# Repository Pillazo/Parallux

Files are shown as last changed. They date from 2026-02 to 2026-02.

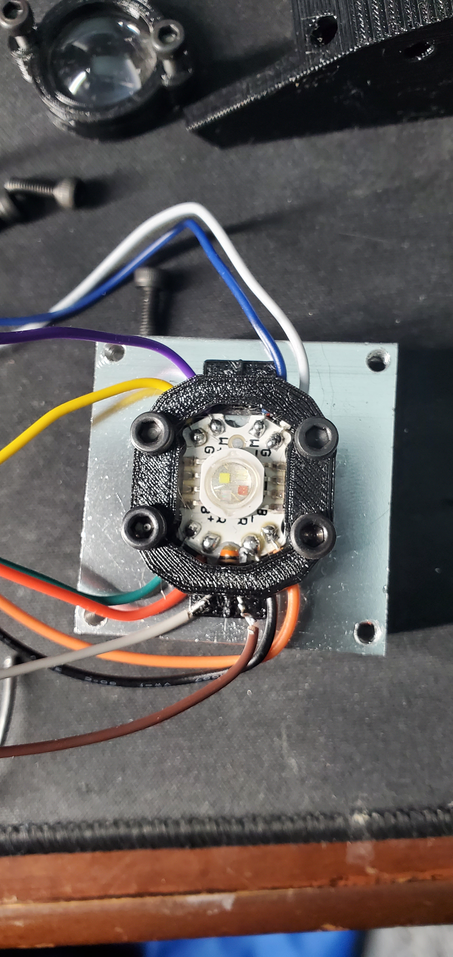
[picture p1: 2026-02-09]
LED Wires.jpg

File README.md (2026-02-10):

The light was designed in Autodesk Fusion 360, but any STEP editor will work. The step file is zipped because the full thing is 250gb-ish

The hardware was designed in KiCad 9.0

The software is arduino IDE, I used ESP32 and Teensy for the microcontrollers

The DMX controller software, which is more sACN anyways, was written in VB.NET

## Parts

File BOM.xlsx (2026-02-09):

Item | Qty | Set | Price per Set | Price | Sub Total | Total | Link
LEDs | 12 | 5 | 14.69 | 2.938 | 35.256 | 735.2235361 | https://www.amazon.com/dp/B0D91GZTSC (https://www.amazon.com/dp/B0D91GZTSC?ref=ppx_yo2ov_dt_b_fed_asin_title&th=1)
Buck Conv 3A | 17 | 8 | 8.89 | 1.11125 | 18.89125 |  | https://www.amazon.com/dp/B08DHS5XVK
Slip Ring | 1 | 1 | 26.58 | 26.58 | 26.58 |  | https://www.amazon.com/dp/B07QPNXXBQ
Lenses | 12 | 10 | 8.59 | 0.859 | 10.308 |  | https://www.amazon.com/dp/B0BR5Q6FN8
Mirrors | 24 | 120 | 9.99 | 0.08325 | 1.998 |  | https://www.amazon.com/dp/B07C1G5RKJ
Heat Sinks | 12 | 4 | 8.99 | 2.2475 | 26.97 |  | https://www.amazon.com/dp/B07SMX1DB7
Aluminum Rod | 1 | 1 | 9.99 | 9.99 | 9.99 |  | https://www.amazon.com/dp/B0CKXY1CXG
ESP32-C3 Super Mini | 4 | 10 | 29.99 | 2.999 | 11.996 |  | https://www.amazon.com/dp/B0DFWG87JS
Stepper Driver | 3 | 6 | 29.99 | 4.998333333 | 14.995 |  | https://www.amazon.com/dp/B08WZFK9KT
Large Steppers | 3 | 5 | 39.95 | 7.99 | 23.97 |  | https://www.amazon.com/dp/B0B38H2ZMR
Fans | 4 | 4 | 7.99 | 1.9975 | 7.99 |  | https://www.amazon.com/dp/B081338TWF
LED Cables | 12 | 10 | 8.99 | 0.899 | 10.788 |  | https://www.amazon.com/dp/B0D3LWW86H
Small Bearing | 28 | 20 | 7.98 | 0.399 | 11.172 |  | https://www.amazon.com/dp/B09PKD8QZZ
Small Steppers | 12 | 5 | 14.59 | 2.918 | 35.016 |  | https://www.amazon.com/dp/B00LPK0E5A
PowerCon Connectors | 1 | 1 | 9.98 | 9.98 | 9.98 |  | https://www.amazon.com/dp/B0CQVB3CF2
Power Supply | 1 | 1 | 28.54 | 28.54 | 28.54 |  | https://www.amazon.com/dp/B013ETVO12
Screw Terminals | 6 | 20 | 14.99 | 0.7495 | 4.497 |  | https://www.amazon.com/dp/B09F6TC7RP
Teensy 4.1 | 1 | 1 | 31.5 | 31.5 | 31.5 |  | https://www.sparkfun.com/teensy-4-1.html
Teensy Ethernet | 1 | 1 | 9.95 | 9.95 | 9.95 |  | https://www.sparkfun.com/ethernet-kit-for-teensy-4-1.html
M3x6mm | 32 | 180 | 7.99 | 0.04438888889 | 1.420444444 |  | https://www.amazon.com/dp/B0DJQGCS36
M3x10mm | 271 | 120 | 7.99 | 0.06658333333 | 18.04408333 |  | https://www.amazon.com/dp/B0DJQGGDP2
M4x6mm | 35 | 120 | 7.99 | 0.06658333333 | 2.330416667 |  | https://www.amazon.com/dp/B0DYS5W46C
M4x12mm | 126 | 120 | 8.49 | 0.07075 | 8.9145 |  | https://www.amazon.com/dp/B0DYRZQQZT
M4x12 Flat Head | 16 | 100 | 8.28 | 0.0828 | 1.3248 |  | https://www.amazon.com/dp/B0CTHK3NLP
M4x20mm | 28 | 120 | 8.99 | 0.07491666667 | 2.097666667 |  | https://www.amazon.com/dp/B0DYSQZHC9
M4x30 Flat Head | 16 | 50 | 8.59 | 0.1718 | 2.7488 |  | https://www.amazon.com/dp/B0FWCTL3XG
m4X35mm | 2 | 60 | 8.49 | 0.1415 | 0.283 |  | https://www.amazon.com/dp/B0DYNFH87B
M6x25mm | 108 | 50 | 8.54 | 0.1708 | 18.4464 |  | https://www.amazon.com/dp/B0FX3Z9DPT
M6x40mm | 56 | 30 | 8.54 | 0.2846666667 | 15.94133333 |  | https://www.amazon.com/dp/B0FX425KPN
M10x30mm | 9 | 10 | 8.79 | 0.879 | 7.911 |  | https://www.amazon.com/dp/B0DJS5RGWF
M10x40mm | 18 | 12 | 12.19 | 1.015833333 | 18.285 |  | https://www.amazon.com/dp/B0DFYL4ZWN
M10x70mm | 19 | 6 | 9.99 | 1.665 | 31.635 |  | https://www.amazon.com/dp/B0D83CJF9C
M3 Nyloc | 7 | 120 | 5.99 | 0.04991666667 | 0.3494166667 |  | https://www.amazon.com/dp/B0D146SHYF
Flat Bearing | 1 | 2 | 9.99 | 4.995 | 4.995 |  | https://www.amazon.com/dp/B0F9B1SBCT
Big Bearing | 5 | 20 | 21.99 | 1.0995 | 5.4975 |  | https://www.amazon.com/dp/B0D5M2LNSG
Aluminum Extrusion 385mm | 2 | 1 | 15.47 | 15.47 | 30.94 |  | https://www.amazon.com/dp/B00J7W1A6U
Aluminum Extrusion 475mm | 5 | 1 | 15.47 | 15.47 | 77.35 |  | https://www.amazon.com/dp/B00J7W1A6U
LightDisc Board | 4 | 10 | 80 | 8 | 32
Thermistor | 12 | 1 | 0.474 | 0.474 | 5.688 |  | https://www.digikey.com/en/products/detail/vishay-beyschlag-draloric-bc-components/NTCLE100E3103JB0/769411
LED Driver | 48 | 1 | 0.3624 | 0.3624 | 17.3952 |  | https://www.digikey.com/en/products/detail/diodes-incorporated/AL8860WT-7/6226978
10K Resistor | 66 | 1 | 0.0112 | 0.0112 | 0.7392 |  | https://www.digikey.com/en/products/detail/yageo/RC1206FR-0710KL/728483
0.015 Resistor | 50 | 1 | 0.098 | 0.098 | 4.9 |  | https://www.digikey.com/en/products/detail/susumu/RL1220T-R015-J/714248
PCA PWM Chip | 4 | 1 | 3.03 | 3.03 | 12.12 |  | https://www.digikey.com/en/products/detail/nxp-usa-inc/PCA9685PW-Q900-118/2406198
MCP IO Chip | 4 | 1 | 1.62 | 1.62 | 6.48 |  | https://www.digikey.com/en/products/detail/microchip-technology/MCP23017-E-SO/894271
Connector 6 Pin | 5 | 1 | 1.88 | 1.88 | 9.4 |  | https://www.digikey.com/en/products/detail/phoenix-contact/1988846/950896
Inductor | 48 | 1 | 0.28 | 0.28 | 13.44 |  | https://www.digikey.com/en/products/detail/tdk-corporation/VLS6045EX-330M/5286699
Diode Schottky | 60 | 1 | 0.207 | 0.207 | 12.42 |  | https://www.digikey.com/en/products/detail/stmicroelectronics/1N5819/1037326
2.2uf Cap | 50 | 1 | 0.0396 | 0.0396 | 1.98 |  | https://www.digikey.com/en/products/detail/samsung-electro-mechanics/CL21B225KPFNNNE/3886846
1uf Cap | 50 | 1 | 0.009 | 0.009 | 0.45 |  | https://www.digikey.com/en/products/detail/samsung-electro-mechanics/CL21B105KAFNNNE/3886724
0.1uf Cap | 10 | 1 | 0.006 | 0.006 | 0.06 |  | https://www.digikey.com/en/products/detail/samsung-electro-mechanics/CL21B104KBCNNNC/3886661
2.2k resistor | 10 | 1 | 0.047 | 0.047 | 0.47 |  | https://www.digikey.com/en/products/detail/te-connectivity-passive-product/CRGCQ1206F2K2/8576416
10uf Cap | 5 | 1 | 0.137 | 0.137 | 0.685 |  | https://www.digikey.com/en/products/detail/panasonic-electronic-components/ECA-1EM100/245007
100uf Cap | 17 | 1 | 0.134 | 0.134 | 2.278 |  | https://www.digikey.com/en/products/detail/panasonic-electronic-components/ECA-0JM101I/2688620
330uf Cap | 4 | 1 | 0.29 | 0.29 | 1.16 |  | https://www.digikey.com/en/products/detail/chinsan-elite/EK1V331MP51012U/16496951
Price per PETG kg: | 13.5
 |  |  |  |  |  |  | Time
 | Qty | grams | PPKG |  |  |  | Hours | Minutes | Total Minutes | Total Time: | 13066
Front Face | 4 | 40.16 | 13.5 | 0.54216 | 2.16864 |  | 3 | 24 | 816 | Hours | 217 | Days: | 9.041666667
Face Star | 1 | 10.8 | 13.5 | 0.1458 | 0.1458 |  |  | 57 | 57 | Minutes | 46
Front Lens Cover | 12 | 6.79 | 13.5 | 0.091665 | 1.09998 |  |  | 40 | 480
Rear Frame x12 | 1 | 12.97 | 13.5 | 0.175095 | 0.175095 |  | 1 | 26 | 86
Front Frame x24 | 1 | 18.11 | 13.5 | 0.244485 | 0.244485 |  | 2 | 3 | 123
Wire Fixture Top x12 | 1 | 12.55 | 13.5 | 0.169425 | 0.169425 |  | 1 | 33 | 93
Wire Fixture Bot x12 | 1 | 6.27 | 13.5 | 0.084645 | 0.084645 |  |  | 50 | 50
Frame | 12 | 20.55 | 13.5 | 0.277425 | 3.3291 |  | 1 | 54 | 1368
Mirror Holder | 12 | 13.06 | 13.5 | 0.17631 | 2.11572 |  | 1 | 9 | 828
Ring Section Single | 4 | 12.9 | 13.5 | 0.17415 | 0.6966 |  | 1 | 15 | 300
Ring Section Dual | 4 | 34.34 | 13.5 | 0.46359 | 1.85436 |  | 3 | 16 | 784
Back Face | 4 | 46.78 | 13.5 | 0.63153 | 2.52612 |  | 4 | 3 | 972
Disc Ring Gear | 4 | 10.59 | 13.5 | 0.142965 | 0.57186 |  | 1 | 1 | 244
Shim - Ironed | 2 | 3.91 | 13.5 | 0.052785 | 0.10557 |  | 1 | 0 | 120
Center Cover Bolts | 1 | 77.91 | 13.5 | 1.051785 | 1.051785 |  | 6 | 15 | 375
Center Cover Threaded | 1 | 78.39 | 13.5 | 1.058265 | 1.058265 |  | 6 | 5 | 365
Inner Shim | 1 | 0.5 | 13.5 | 0.00675 | 0.00675 |  | 0 | 4 | 4
Disc Inner Gear | 1 | 11.17 | 13.5 | 0.150795 | 0.150795 |  | 0 | 59 | 59
Slip Ring Connector | 1 | 10.5 | 13.5 | 0.14175 | 0.14175 |  | 0 | 54 | 54
Motor Mount Adapter | 1 | 22.36 | 13.5 | 0.30186 | 0.30186 |  | 1 | 47 | 107
Disc Mount | 1 | 24.99 | 13.5 | 0.337365 | 0.337365 |  | 2 | 12 | 132
Wire Cap x6 | 1 | 3.32 | 13.5 | 0.04482 | 0.04482 |  | 0 | 23 | 23
Wire Cap Front | 1 | 0.72 | 13.5 | 0.00972 | 0.00972 |  | 0 | 7 | 7
Counter weight | 1 | 194.17 | 13.5 | 2.621295 | 2.621295 |  | 14 | 57 | 897
Ring Drive Gear | 2 | 28.65 | 13.5 | 0.386775 | 0.77355 |  | 2 | 17 | 274
Tilt Cap | 2 | 8.77 | 13.5 | 0.118395 | 0.23679 |  | 0 | 48 | 96
tilt Motor Mount | 1 | 27.55 | 13.5 | 0.371925 | 0.371925 |  | 2 | 14 | 134
Motor Mount Offset 1 | 1 | 7.27 | 13.5 | 0.098145 | 0.098145 |  | 0 | 41 | 41
Motor Mount Offset 2 | 1 | 6.88 | 13.5 | 0.09288 | 0.09288 |  | 0 | 39 | 39
Tilt Upright 1 Lower | 1 | 97.65 | 13.5 | 1.318275 | 1.318275 |  | 6 | 55 | 415
Tilt Upright 1 Upper | 1 | 36.12 | 13.5 | 0.48762 | 0.48762 |  | 2 | 49 | 169
Tilt Upright 2 Lower | 1 | 96.46 | 13.5 | 1.30221 | 1.30221 |  | 6 | 41 | 401
Tilt Upright 2 Upper | 1 | 35.89 | 13.5 | 0.484515 | 0.484515 |  | 2 | 50 | 170
Pipe Cap | 1 | 11.32 | 13.5 | 0.15282 | 0.15282 |  | 0 | 54 | 54
Tilt Gear 1 | 1 | 57.52 | 13.5 | 0.77652 | 0.77652 |  | 4 | 40 | 280
Tilt Gear 2 | 1 | 57.58 | 13.5 | 0.77733 | 0.77733 |  | 4 | 41 | 281
Pan Gear Mount | 2 | 101.31 | 13.5 | 1.367685 | 2.73537 |  | 7 | 30 | 900
Pan Gear Idle | 2 | 92.7 | 13.5 | 1.25145 | 2.5029 |  | 7 | 0 | 840
Pan Center | 1 | 2.95 | 13.5 | 0.039825 | 0.039825 |  | 0 | 21 | 21
Cable Chain x10 | 1 | 12.07 | 13.5 | 0.162945 | 0.162945 |  | 1 | 23 | 83
Cable Chain Base | 1 | 3.46 | 13.5 | 0.04671 | 0.04671 |  | 0 | 24 | 24
Pan Base Mount | 1 | 24.89 | 13.5 | 0.336015 | 0.336015 |  | 2 | 2 | 122
Pan Chain Attach Holes | 1 | 5.4 | 13.5 | 0.0729 | 0.0729 |  | 0 | 32 | 32
Pan Chain Attach Threaded | 1 | 5.03 | 13.5 | 0.067905 | 0.067905 |  | 0 | 29 | 29
Power Supply Mount x4 | 1 | 17.45 | 13.5 | 0.235575 | 0.235575 |  | 1 | 33 | 93
PS Cover Upper | 1 | 20.17 | 13.5 | 0.272295 | 0.272295 |  | 1 | 47 | 107
PS Cover Lower | 1 | 22.2 | 13.5 | 0.2997 | 0.2997 |  | 1 | 57 | 117
 |  |  | 13.5 | 0 | 0 |  |  |  | 0
 |  |  | 13.5 | 0 | 0 |  |  |  | 0
 |  |  | 13.5 | 0 | 0 |  |  |  | 0
 |  |  | 13.5 | 0 | 0 |  |  |  | 0
 |  |  | 13.5 | 0 | 0 |  |  |  | 0
 |  |  | 13.5 | 0 | 0 |  |  |  | 0
 |  |  | 13.5 | 0 | 0 |  |  |  | 0
 |  |  | 13.5 | 0 | 0 |  |  |  | 0
 |  |  | 13.5 | 0 | 0 |  |  |  | 0
 |  |  | 13.5 | 0 | 0 |  |  |  | 0

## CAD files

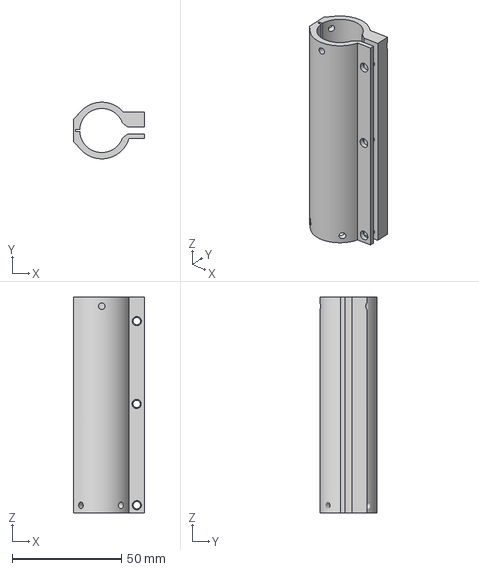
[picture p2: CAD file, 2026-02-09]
3MF Files/CenterPostGuide.3mf
32.6 x 26.0 x 99.0 mm

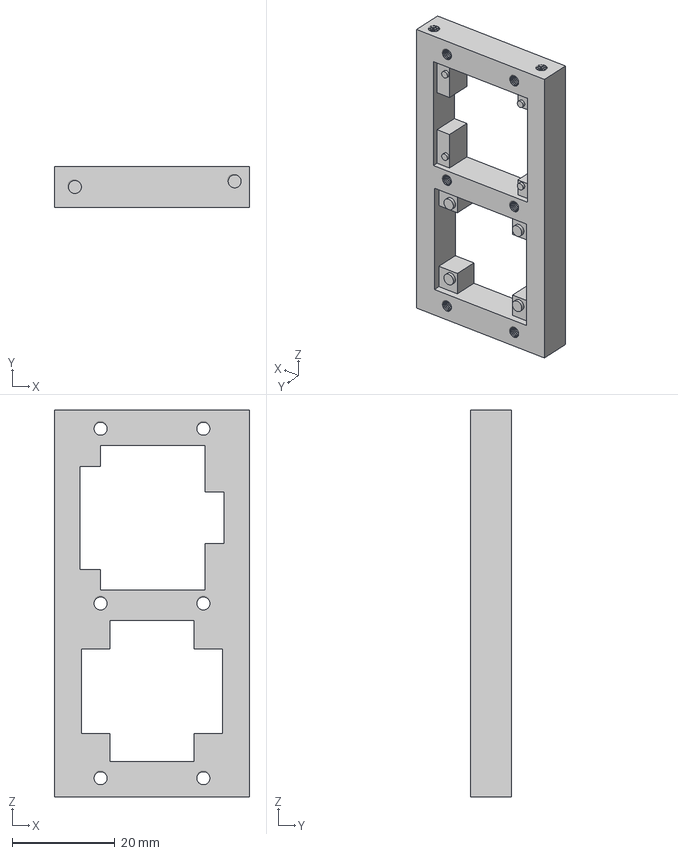
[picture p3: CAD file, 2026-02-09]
3MF Files/NaviBase.3mf
38.0 x 8.00 x 75.3 mm

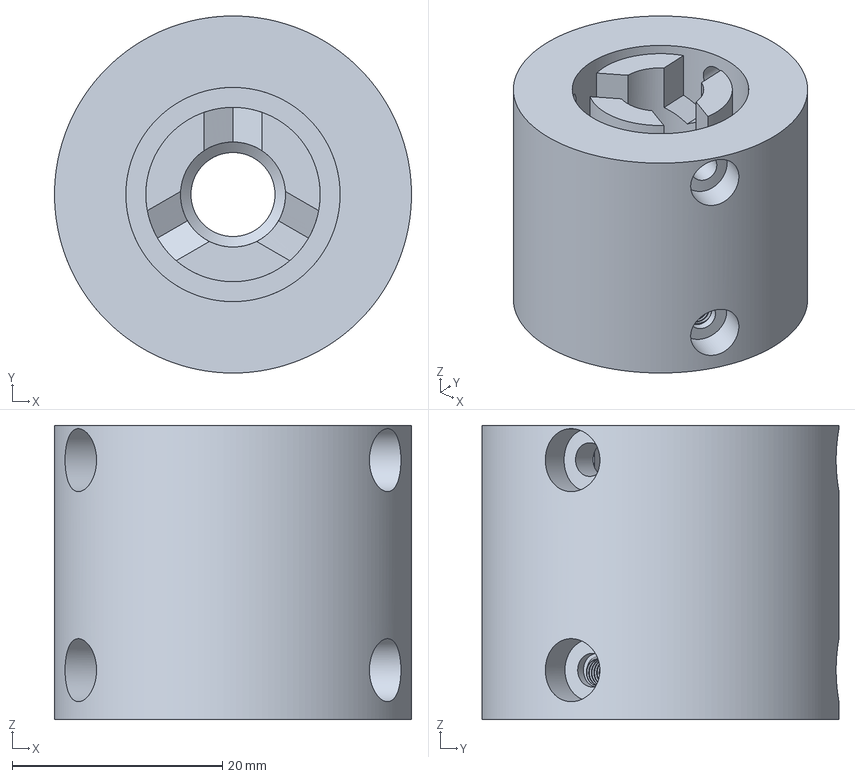
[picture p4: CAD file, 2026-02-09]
3MF Files/SlipRing Connector.3mf
34.0 x 34.0 x 28.0 mm

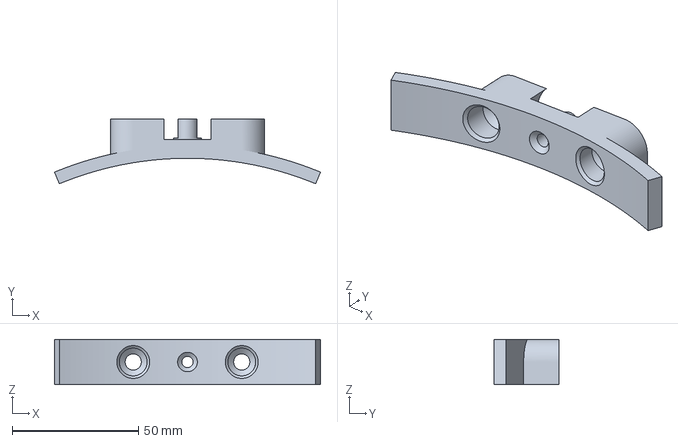
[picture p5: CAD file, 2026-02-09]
3MF Files/Pan Bearing CapSlide.3mf
105.4 x 25.6 x 18.0 mm

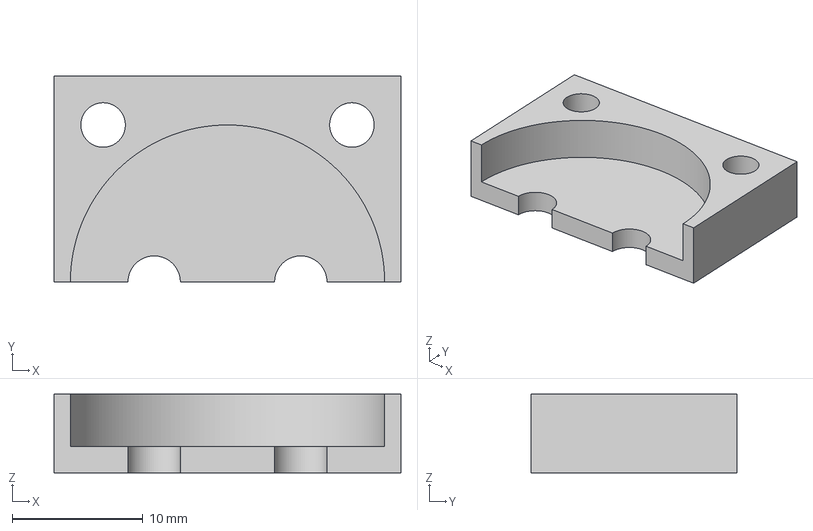
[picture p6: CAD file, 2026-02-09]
3MF Files/PowerConBack.3mf
26.5 x 15.8 x 6.00 mm

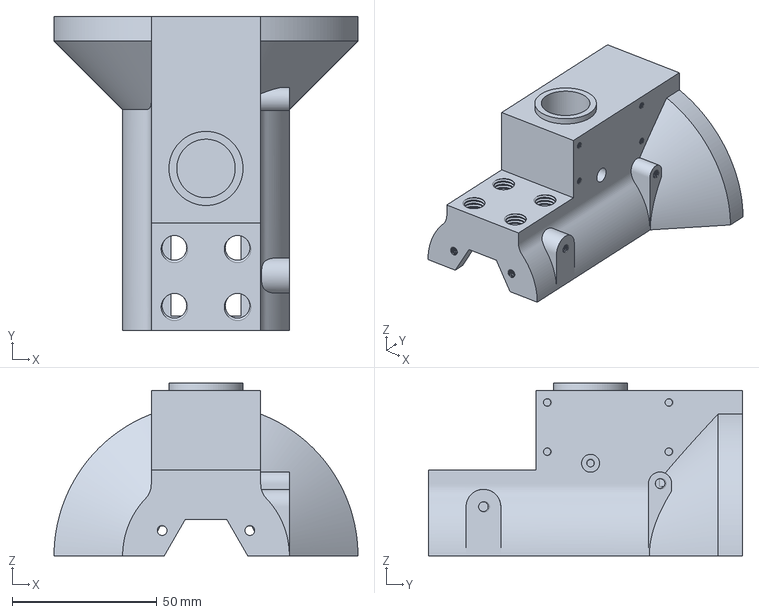
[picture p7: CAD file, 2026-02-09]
3MF Files/CenterCoverThreaded.3mf
105.0 x 108.5 x 59.7 mm

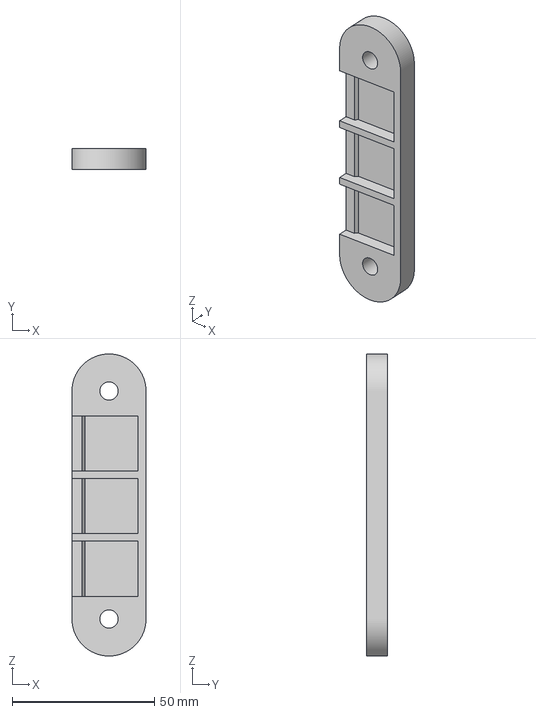
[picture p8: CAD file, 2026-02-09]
3MF Files/WagoHolder Back.3mf
26.0 x 7.50 x 106.0 mm

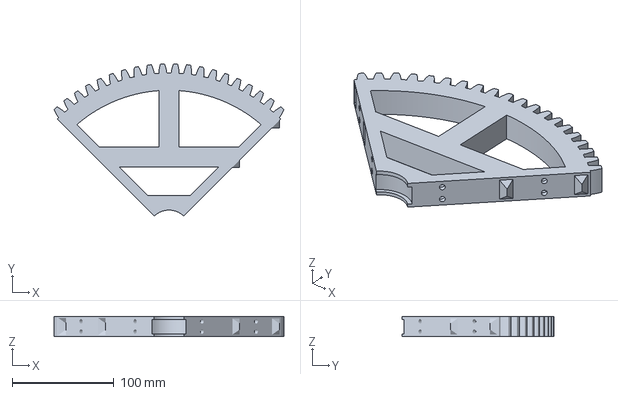
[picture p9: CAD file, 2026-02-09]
3MF Files/Pan Gear Idle 2.3mf
225.5 x 149.4 x 20.0 mm

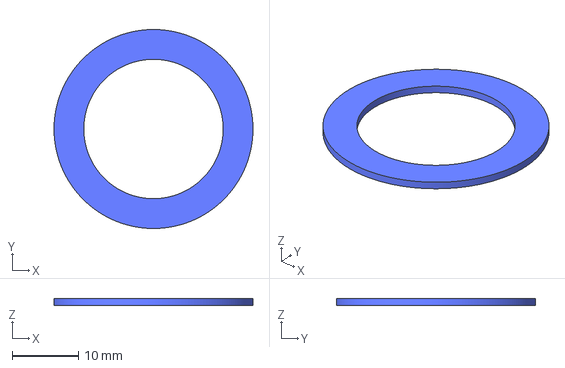
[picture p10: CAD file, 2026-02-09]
3MF Files/Inner Shim.3mf
30.0 x 30.0 x 1.00 mm

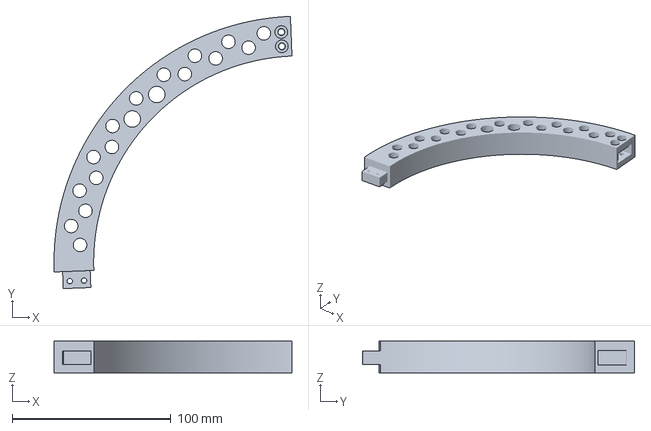
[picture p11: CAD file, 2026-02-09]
3MF Files/TiltRingGearAttach.3mf
149.9 x 171.4 x 20.0 mm

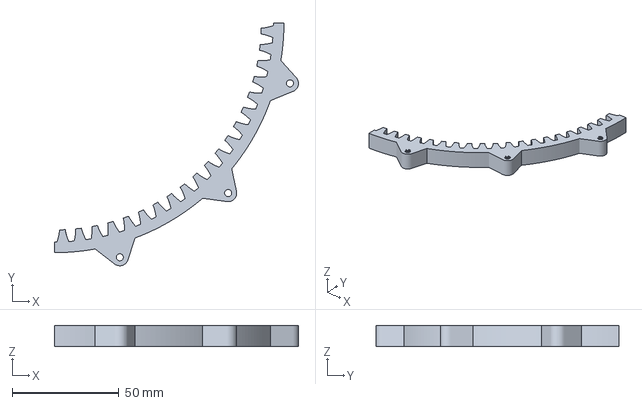
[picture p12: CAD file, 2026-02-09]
3MF Files/Disc Ring Gear.3mf
114.2 x 113.6 x 10.0 mm

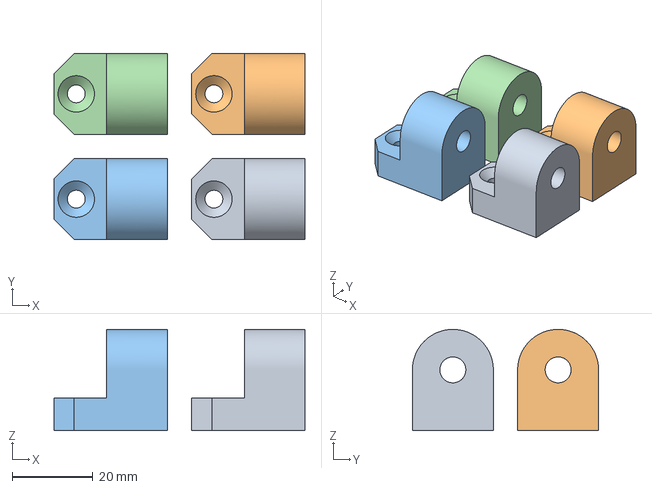
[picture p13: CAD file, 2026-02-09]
3MF Files/PowerSupplyMount.3mf
62.0 x 46.0 x 25.0 mm

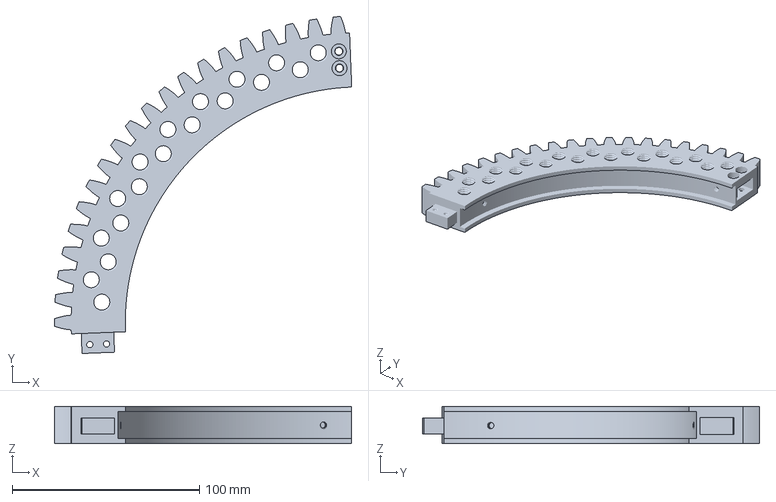
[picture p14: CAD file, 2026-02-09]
3MF Files/Tilt Ring Gear Section.3mf
159.1 x 180.2 x 20.0 mm

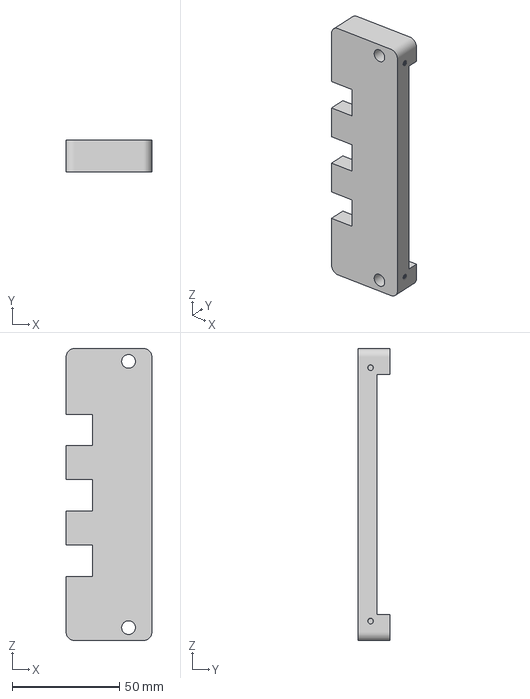
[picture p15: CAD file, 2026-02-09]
3MF Files/Electronics Mount 1.3mf
40.0 x 14.8 x 136.0 mm

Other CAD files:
3MF Files/Panel Connector Right.3mf
3MF Files/Pan Bearing Holder Front.3mf
3MF Files/Tilt Gear 1.3mf
3MF Files/Electronics Mount 2.3mf
3MF Files/Aluminum Nut 2x 16mm.3mf
3MF Files/Aluminum Nut.3mf
3MF Files/Axel Key.3mf
3MF Files/Back Face.3mf
3MF Files/Base Joiner Corner.3mf
3MF Files/Base Joiner Lower.3mf
3MF Files/Base Joiner Upper Enet.3mf
3MF Files/Base Joiner Upper-PC.3mf
3MF Files/Base Joiner Upper.3mf
3MF Files/Bearing Cap.3mf
3MF Files/CBSheelThreads.3mf
3MF Files/CBShellHole.3mf
3MF Files/Cable Chain Base.3mf
3MF Files/Cable Chain.3mf
3MF Files/CenterCoverBolts.3mf
3MF Files/Disc Inner Gear.3mf
3MF Files/DiscMount.3mf
3MF Files/Electronics Lid.3mf
3MF Files/EthernetLid.3mf
3MF Files/FacePlateStar.3mf
3MF Files/Fan Grill.3mf
3MF Files/Frame.3mf
3MF Files/FrontFace.3mf
3MF Files/FrontFrame.3mf
3MF Files/FrontLensCover.3mf
3MF Files/MirrorHolder.3mf
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

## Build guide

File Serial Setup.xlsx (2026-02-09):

Index | DMX Address | From Master Chip | From Board 1 | From Board 2 | From Board 3 | From Board 4
0 | 1 | D | D | D | D | D
1 | 2 | Light 1 Hue | Light 4 Hue | Light 7 Hue | Light 10 Hue | Light 1 Temp Ch1
2 | 3 | Light 1 Sat | Light 4 Sat | Light 7 Sat | Light 10 Sat | Light 1 Temp Ch2
3 | 4 | Light 1 Value | Light 4 Value | Light 7 Value | Light 10 Value | Light 1 Temp Per
4 | 5 | Light 1 Mirror | Light 4 Mirror | Light 7 Mirror | Light 10 Mirror | Light 1 Temp Ch3
5 | 6 | Light 2 Hue | Light 5 Hue | Light 8 Hue | Light 11 Hue | Light 2 Temp Ch1
6 | 7 | Light 2 Sat | Light 5 Sat | Light 8 Sat | Light 11 Sat | Light 2 Temp Ch2
7 | 8 | Light 2 Value | Light 5 Value | Light 8 Value | Light 11 Value | Light 2 Temp Per
8 | 9 | Light 2 Mirror | Light 5 Mirror | Light 8 Mirror | Light 11 Mirror | Light 2 Temp Ch3
9 | 10 | Light 3 Hue | Light 6 Hue | Light 9 Hue | Light 12 Hue | Light 3 Temp Ch1
10 | 11 | Light 3 Sat | Light 6 Sat | Light 9 Sat | Light 12 Sat | Light 3 Temp Ch2
11 | 12 | Light 3 Value | Light 6 Value | Light 9 Value | Light 12 Value | Light 3 Temp Per
12 | 13 | Light 3 Mirror | Light 6 Mirror | Light 9 Mirror | Light 12 Mirror | Light 3 Temp Ch3
13 | 14 | Light 4 Hue | Light 7 Hue | Light 10 Hue | Light 1 Temp Ch1 | Light 4 Temp Ch1
14 | 15 | Light 4 Sat | Light 7 Sat | Light 10 Sat | Light 1 Temp Ch2 | Light 4 Temp Ch2
15 | 16 | Light 4 Value | Light 7 Value | Light 10 Value | Light 1 Temp Per | Light 4 Temp Per
16 | 17 | Light 4 Mirror | Light 7 Mirror | Light 10 Mirror | Light 1 Temp Ch3 | Light 4 Temp Ch3
17 | 18 | Light 5 Hue | Light 8 Hue | Light 11 Hue | Light 2 Temp Ch1 | Light 5 Temp Ch1
18 | 19 | Light 5 Sat | Light 8 Sat | Light 11 Sat | Light 2 Temp Ch2 | Light 5 Temp Ch2
19 | 20 | Light 5 Value | Light 8 Value | Light 11 Value | Light 2 Temp Per | Light 5 Temp Per
20 | 21 | Light 5 Mirror | Light 8 Mirror | Light 11 Mirror | Light 2 Temp Ch3 | Light 5 Temp Ch3
21 | 22 | Light 6 Hue | Light 9 Hue | Light 12 Hue | Light 3 Temp Ch1 | Light 6 Temp Ch1
22 | 23 | Light 6 Sat | Light 9 Sat | Light 12 Sat | Light 3 Temp Ch2 | Light 6 Temp Ch2
23 | 24 | Light 6 Value | Light 9 Value | Light 12 Value | Light 3 Temp Per | Light 6 Temp Per
24 | 25 | Light 6 Mirror | Light 9 Mirror | Light 12 Mirror | Light 3 Temp Ch3 | Light 6 Temp Ch3
25 | 26 | Light 7 Hue | Light 10 Hue | Light 1 Temp Ch1 | Light 4 Temp Ch1 | Light 7 Temp Ch1
26 | 27 | Light 7 Sat | Light 10 Sat | Light 1 Temp Ch2 | Light 4 Temp Ch2 | Light 7 Temp Ch2
27 | 28 | Light 7 Value | Light 10 Value | Light 1 Temp Per | Light 4 Temp Per | Light 7 Temp Per
28 | 29 | Light 7 Mirror | Light 10 Mirror | Light 1 Temp Ch3 | Light 4 Temp Ch3 | Light 7 Temp Ch3
29 | 30 | Light 8 Hue | Light 11 Hue | Light 2 Temp Ch1 | Light 5 Temp Ch1 | Light 8 Temp Ch1
30 | 31 | Light 8 Sat | Light 11 Sat | Light 2 Temp Ch2 | Light 5 Temp Ch2 | Light 8 Temp Ch2
31 | 32 | Light 8 Value | Light 11 Value | Light 2 Temp Per | Light 5 Temp Per | Light 8 Temp Per
32 | 33 | Light 8 Mirror | Light 11 Mirror | Light 2 Temp Ch3 | Light 5 Temp Ch3 | Light 8 Temp Ch3
33 | 34 | Light 9 Hue | Light 12 Hue | Light 3 Temp Ch1 | Light 6 Temp Ch1 | Light 9 Temp Ch1
34 | 35 | Light 9 Sat | Light 12 Sat | Light 3 Temp Ch2 | Light 6 Temp Ch2 | Light 9 Temp Ch2
35 | 36 | Light 9 Value | Light 12 Value | Light 3 Temp Per | Light 6 Temp Per | Light 9 Temp Per
36 | 37 | Light 9 Mirror | Light 12 Mirror | Light 3 Temp Ch3 | Light 6 Temp Ch3 | Light 9 Temp Ch3
37 | 38 | Light 10 Hue | Light 1 Temp Ch1 | Light 4 Temp Ch1 | Light 7 Temp Ch1 | Light 10 Temp Ch1
38 | 39 | Light 10 Sat | Light 1 Temp Ch2 | Light 4 Temp Ch2 | Light 7 Temp Ch2 | Light 10 Temp Ch2
39 | 40 | Light 10 Value | Light 1 Temp Per | Light 4 Temp Per | Light 7 Temp Per | Light 10 Temp Per
40 | 41 | Light 10 Mirror | Light 1 Temp Ch3 | Light 4 Temp Ch3 | Light 7 Temp Ch3 | Light 10 Temp Ch3
41 | 42 | Light 11 Hue | Light 2 Temp Ch1 | Light 5 Temp Ch1 | Light 8 Temp Ch1 | Light 11 Temp Ch1
42 | 43 | Light 11 Sat | Light 2 Temp Ch2 | Light 5 Temp Ch2 | Light 8 Temp Ch2 | Light 11 Temp Ch2
43 | 44 | Light 11 Value | Light 2 Temp Per | Light 5 Temp Per | Light 8 Temp Per | Light 11 Temp Per
44 | 45 | Light 11 Mirror | Light 2 Temp Ch3 | Light 5 Temp Ch3 | Light 8 Temp Ch3 | Light 11 Temp Ch3
45 | 46 | Light 12 Hue | Light 3 Temp Ch1 | Light 6 Temp Ch1 | Light 9 Temp Ch1 | Light 12 Temp Ch1
46 | 47 | Light 12 Sat | Light 3 Temp Ch2 | Light 6 Temp Ch2 | Light 9 Temp Ch2 | Light 12 Temp Ch2
47 | 48 | Light 12 Value | Light 3 Temp Per | Light 6 Temp Per | Light 9 Temp Per | Light 12 Temp Per
48 | 49 | Light 12 Mirror | Light 3 Temp Ch3 | Light 6 Temp Ch3 | Light 9 Temp Ch3 | Light 12 Temp Ch3
49 | 50
50 | 51
51 | 52
52 | 53
53 | 54
54 | 55
55 | 56
56 | 57
57 | 58
58 | 59
59 | 60
60 | 61
61 | 62
62 | 63
63 | 64
64 | 65
65 | 66
66 | 67
67 | 68
68 | 69
69 | 70

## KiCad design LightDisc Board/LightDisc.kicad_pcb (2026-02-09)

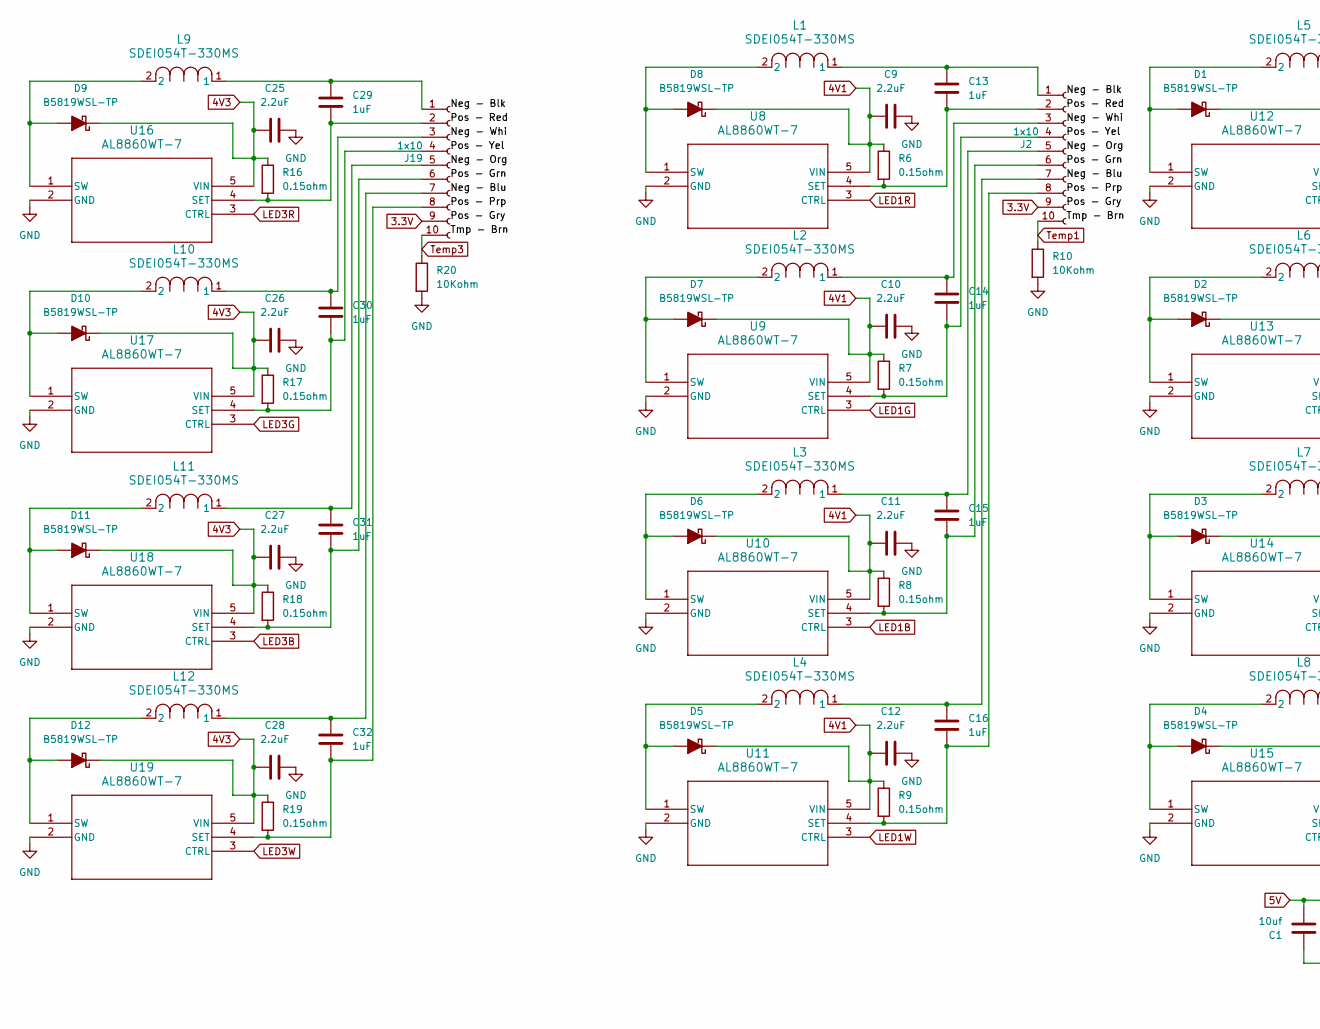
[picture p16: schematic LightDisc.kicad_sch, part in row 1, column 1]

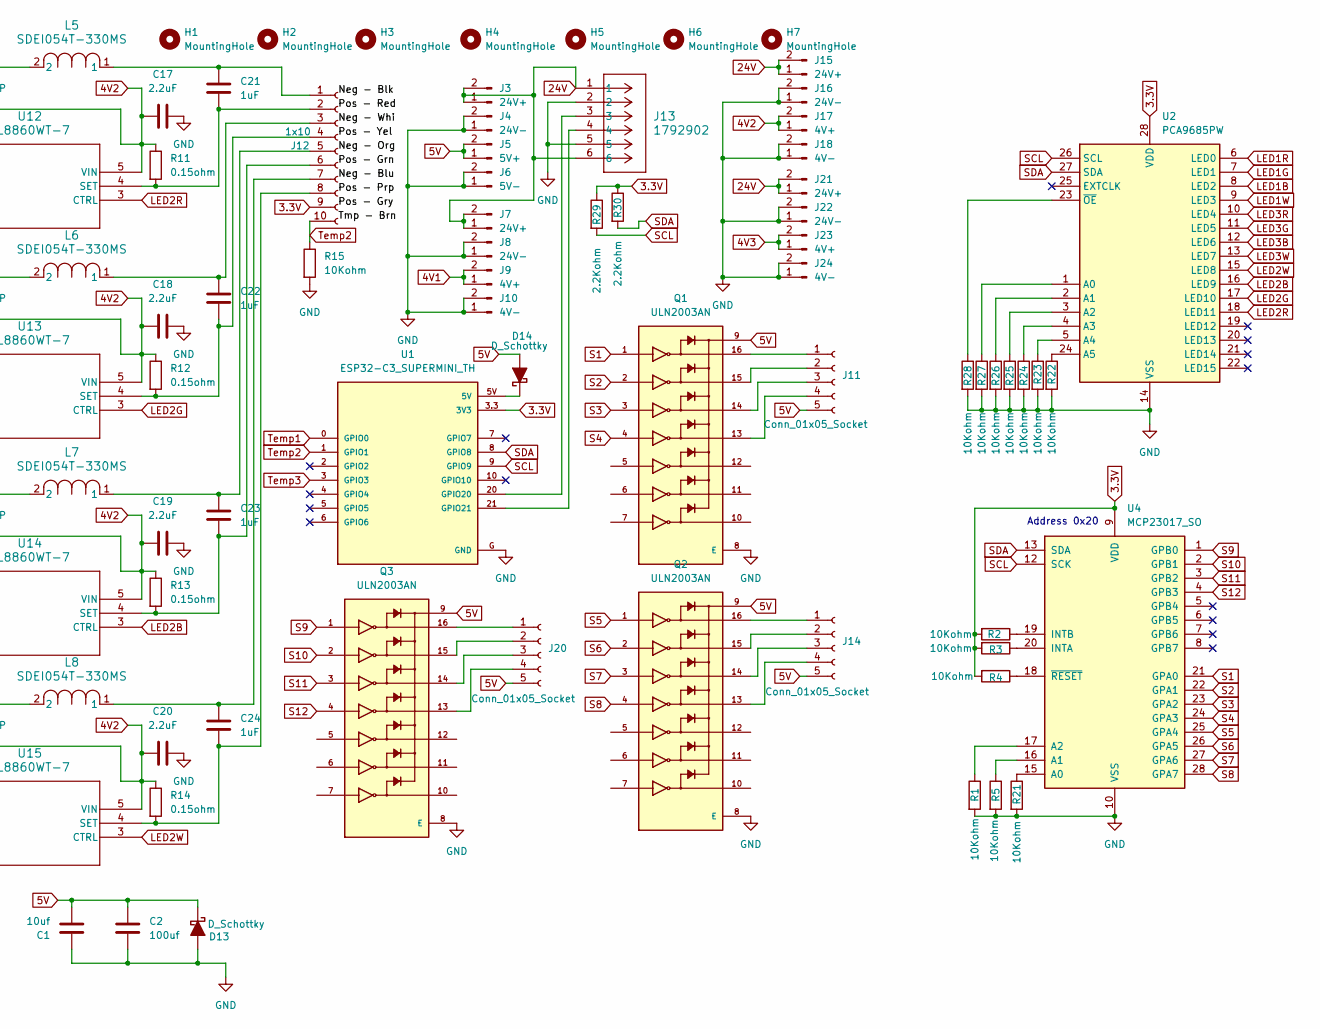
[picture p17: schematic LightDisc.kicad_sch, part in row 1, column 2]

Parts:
C1: 10uf; CP_Radial_D5.0mm_P2.50mm
C2: 100uf; CP_Radial_D5.0mm_P2.50mm
C9, C10, C11, C12, C17, C18, C19, C20, C25, C26, C27, C28: 2.2uF; C_0603_1608Metric
C13, C14, C15, C16, C21, C22, C23, C24, C29, C30, C31, C32: 1uF; C_0603_1608Metric
D1, D2, D3, D4, D5, D6, D7, D8, D9, D10, D11, D12: B5819WSL-TP; D_SOD-323F
D13, D14: D_Schottky; D_SOD-323F
H1, H2, H3, H4, H5, H6, H7: MountingHole; MountingHole_3.2mm_M3
J2, J12, J19: 1x10; JST_EH_B10B-EH-A_1x10_P2.50mm_Vertical
J3, J7, J15, J21: 24V+; PinSocket_1x02_P2.54mm_Vertical
J4, J8, J16, J22: 24V-; PinSocket_1x02_P2.54mm_Vertical
J5: 5V+; PinSocket_1x02_P2.54mm_Vertical
J6: 5V-; PinSocket_1x02_P2.54mm_Vertical
J9, J17, J23: 4V+; PinSocket_1x02_P2.54mm_Vertical
J10, J18, J24: 4V-; PinSocket_1x02_P2.54mm_Vertical
J11, J14, J20: Conn_01x05_Socket; PinSocket_1x05_P2.54mm_Vertical
J13: 1792902; CONN_1792902_PXC
L1, L2, L3, L4, L5, L6, L7, L8, L9, L10, L11, L12: SDEI054T-330MS; IND_SDEI054T-330MS_CYN
Q1, Q2, Q3: ULN2003AN; CERDIP-16_W7.62mm_SideBrazed_LongPads_Socket; PARTREV P
R1, R2, R3, R4, R5, R10, R15, R20, R21, R22, R23, R24, R25, R26, R27, R28: 10Kohm; R_1206_3216Metric
R6, R7, R8, R9, R11, R12, R13, R14, R16, R17, R18, R19: 0.15ohm; R_0805_2012Metric
R29, R30: 2.2Kohm; R_1206_3216Metric
U1: ESP32-C3_SUPERMINI_TH; MODULE_ESP32-C3_SUPERMINI_TH
U2: PCA9685PW; TSSOP-28_4.4x9.7mm_P0.65mm
U4: MCP23017_SO; SOIC-28W_7.5x17.9mm_P1.27mm
U8, U9, U10, U11, U12, U13, U14, U15, U16, U17, U18, U19: AL8860WT-7; TSOT25_WT_DIO

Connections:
3.3V: J2.9, J12.9, J19.9, R2.2, R3.2, R4.2, R29.1, R30.1, U1.3.3 (3V3), U2.28 (VDD), U4.9 (VDD)
4V1: C9.2, C10.2, C11.2, C12.2, D5.1 (K), D6.1 (K), D7.1 (K), D8.1 (K), J9.1, J9.2, R6.1, R7.1, R8.1, R9.1, U8.5 (VIN), U9.5 (VIN), U10.5 (VIN), U11.5 (VIN)
4V2: C17.2, C18.2, C19.2, C20.2, D1.1 (K), D2.1 (K), D3.1 (K), D4.1 (K), J17.1, J17.2, R11.1, R12.1, R13.1, R14.1, U12.5 (VIN), U13.5 (VIN), U14.5 (VIN), U15.5 (VIN)
4V3: C25.2, C26.2, C27.2, C28.2, D9.1 (K), D10.1 (K), D11.1 (K), D12.1 (K), J23.1, J23.2, R16.1, R17.1, R18.1, R19.1, U16.5 (VIN), U17.5 (VIN), U18.5 (VIN), U19.5 (VIN)
5V: C1.2, C2.2, D13.1 (K), D14.2 (A), J5.1, J5.2, J11.5, J14.5, J20.5, Q1.9, Q2.9, Q3.9
24V: J3.1, J3.2, J7.1, J7.2, J13.1, J13.6, J15.1, J15.2, J21.1, J21.2
GND: C1.1, C2.1, C9.1, C10.1, C11.1, C12.1, C17.1, C18.1, C19.1, C20.1, C25.1, C26.1, C27.1, C28.1, D13.2 (A), J4.1, J4.2, J6.1, J6.2, J8.1, J8.2, J10.1, J10.2, J13.2, J13.5, J16.1, J16.2, J18.1, J18.2, J22.1, J22.2, J24.1, J24.2, Q1.8 (E), Q2.8 (E), Q3.8 (E), R1.2, R5.2, R10.2, R15.2, R20.2, R21.2, R22.2, R23.2, R24.2, R25.2, R26.2, R27.2, R28.2, U1.G (GND), U2.14 (VSS), U4.10 (VSS), U8.2 (GND), U9.2 (GND), U10.2 (GND), U11.2 (GND), U12.2 (GND), U13.2 (GND), U14.2 (GND), U15.2 (GND), U16.2 (GND), U17.2 (GND), U18.2 (GND), U19.2 (GND)
LED1B: U2.8 (LED2), U10.3 (CTRL)
LED1G: U2.7 (LED1), U9.3 (CTRL)
LED1R: U2.6 (LED0), U8.3 (CTRL)
LED1W: U2.9 (LED3), U11.3 (CTRL)
LED2B: U2.16 (LED9), U14.3 (CTRL)
LED2G: U2.17 (LED10), U13.3 (CTRL)
LED2R: U2.18 (LED11), U12.3 (CTRL)
LED2W: U2.15 (LED8), U15.3 (CTRL)
LED3B: U2.12 (LED6), U18.3 (CTRL)
LED3G: U2.11 (LED5), U17.3 (CTRL)
LED3R: U2.10 (LED4), U16.3 (CTRL)
LED3W: U2.13 (LED7), U19.3 (CTRL)
unnamed: D1.2 (A), L5.2, U12.1 (SW)
unnamed: D2.2 (A), L6.2, U13.1 (SW)
unnamed: D3.2 (A), L7.2, U14.1 (SW)
unnamed: D4.2 (A), L8.2, U15.1 (SW)
unnamed: D5.2 (A), L4.2, U11.1 (SW)
unnamed: D6.2 (A), L3.2, U10.1 (SW)
unnamed: D7.2 (A), L2.2, U9.1 (SW)
unnamed: D8.2 (A), L1.2, U8.1 (SW)
unnamed: D9.2 (A), L9.2, U16.1 (SW)
unnamed: D10.2 (A), L10.2, U17.1 (SW)
unnamed: D11.2 (A), L11.2, U18.1 (SW)
unnamed: D12.2 (A), L12.2, U19.1 (SW)
unnamed: D14.1 (K), U1.5V
unnamed: C13.1, J2.1, L1.1
unnamed: C13.2, J2.2, R6.2, U8.4 (SET)
unnamed: C14.1, J2.3, L2.1
unnamed: C14.2, J2.4, R7.2, U9.4 (SET)
unnamed: C15.1, J2.5, L3.1
unnamed: C15.2, J2.6, R8.2, U10.4 (SET)
unnamed: C16.1, J2.7, L4.1
unnamed: C16.2, J2.8, R9.2, U11.4 (SET)
unnamed: J11.1, Q1.16
unnamed: J11.2, Q1.15
unnamed: J11.3, Q1.14
unnamed: J11.4, Q1.13
unnamed: C21.1, J12.1, L5.1
unnamed: C21.2, J12.2, R11.2, U12.4 (SET)
unnamed: C22.1, J12.3, L6.1
unnamed: C22.2, J12.4, R12.2, U13.4 (SET)
unnamed: C23.1, J12.5, L7.1
unnamed: C23.2, J12.6, R13.2, U14.4 (SET)
unnamed: C24.1, J12.7, L8.1
unnamed: C24.2, J12.8, R14.2, U15.4 (SET)
unnamed: J14.1, Q2.16
unnamed: J14.2, Q2.15
unnamed: J14.3, Q2.14
unnamed: J14.4, Q2.13
unnamed: C29.1, J19.1, L9.1
unnamed: C29.2, J19.2, R16.2, U16.4 (SET)
unnamed: C30.1, J19.3, L10.1
unnamed: C30.2, J19.4, R17.2, U17.4 (SET)
unnamed: C31.1, J19.5, L11.1
unnamed: C31.2, J19.6, R18.2, U18.4 (SET)
unnamed: C32.1, J19.7, L12.1
unnamed: C32.2, J19.8, R19.2, U19.4 (SET)
unnamed: J20.1, Q3.16
unnamed: J20.2, Q3.15
unnamed: J20.3, Q3.14
unnamed: J20.4, Q3.13
unnamed: J13.3, U1.20 (GPIO20)
unnamed: J13.4, U1.21 (GPIO21)
unnamed: R27.1, U2.1 (A0)
unnamed: R26.1, U2.2 (A1)
unnamed: R25.1, U2.3 (A2)
unnamed: R24.1, U2.4 (A3)
unnamed: R23.1, U2.5 (A4)
unnamed: R22.1, U2.24 (A5)
unnamed: R28.1, U2.23 (~OE)
unnamed: R21.1, U4.15 (A0)
unnamed: R5.1, U4.16 (A1)
unnamed: R1.1, U4.17 (A2)
unnamed: R3.1, U4.20 (INTA)
unnamed: R2.1, U4.19 (INTB)
unnamed: R4.1, U4.18 (~RESET)
S1: Q1.1, U4.21 (GPA0)
S2: Q1.2, U4.22 (GPA1)
S3: Q1.3, U4.23 (GPA2)
S4: Q1.4, U4.24 (GPA3)
S5: Q2.1, U4.25 (GPA4)
S6: Q2.2, U4.26 (GPA5)
S7: Q2.3, U4.27 (GPA6)
S8: Q2.4, U4.28 (GPA7)
S9: Q3.1, U4.1 (GPB0)
S10: Q3.2, U4.2 (GPB1)
S11: Q3.3, U4.3 (GPB2)
S12: Q3.4, U4.4 (GPB3)
SCL: R29.2, U1.9 (GPIO9), U2.26 (SCL), U4.12 (SCK)
SDA: R30.2, U1.8 (GPIO8), U2.27 (SDA), U4.13 (SDA)
Temp1: J2.10, R10.1, U1.0 (GPIO0)
Temp2: J12.10, R15.1, U1.1 (GPIO1)
Temp3: J19.10, R20.1, U1.2 (GPIO2), U1.3 (GPIO3)

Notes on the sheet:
Address 0x20

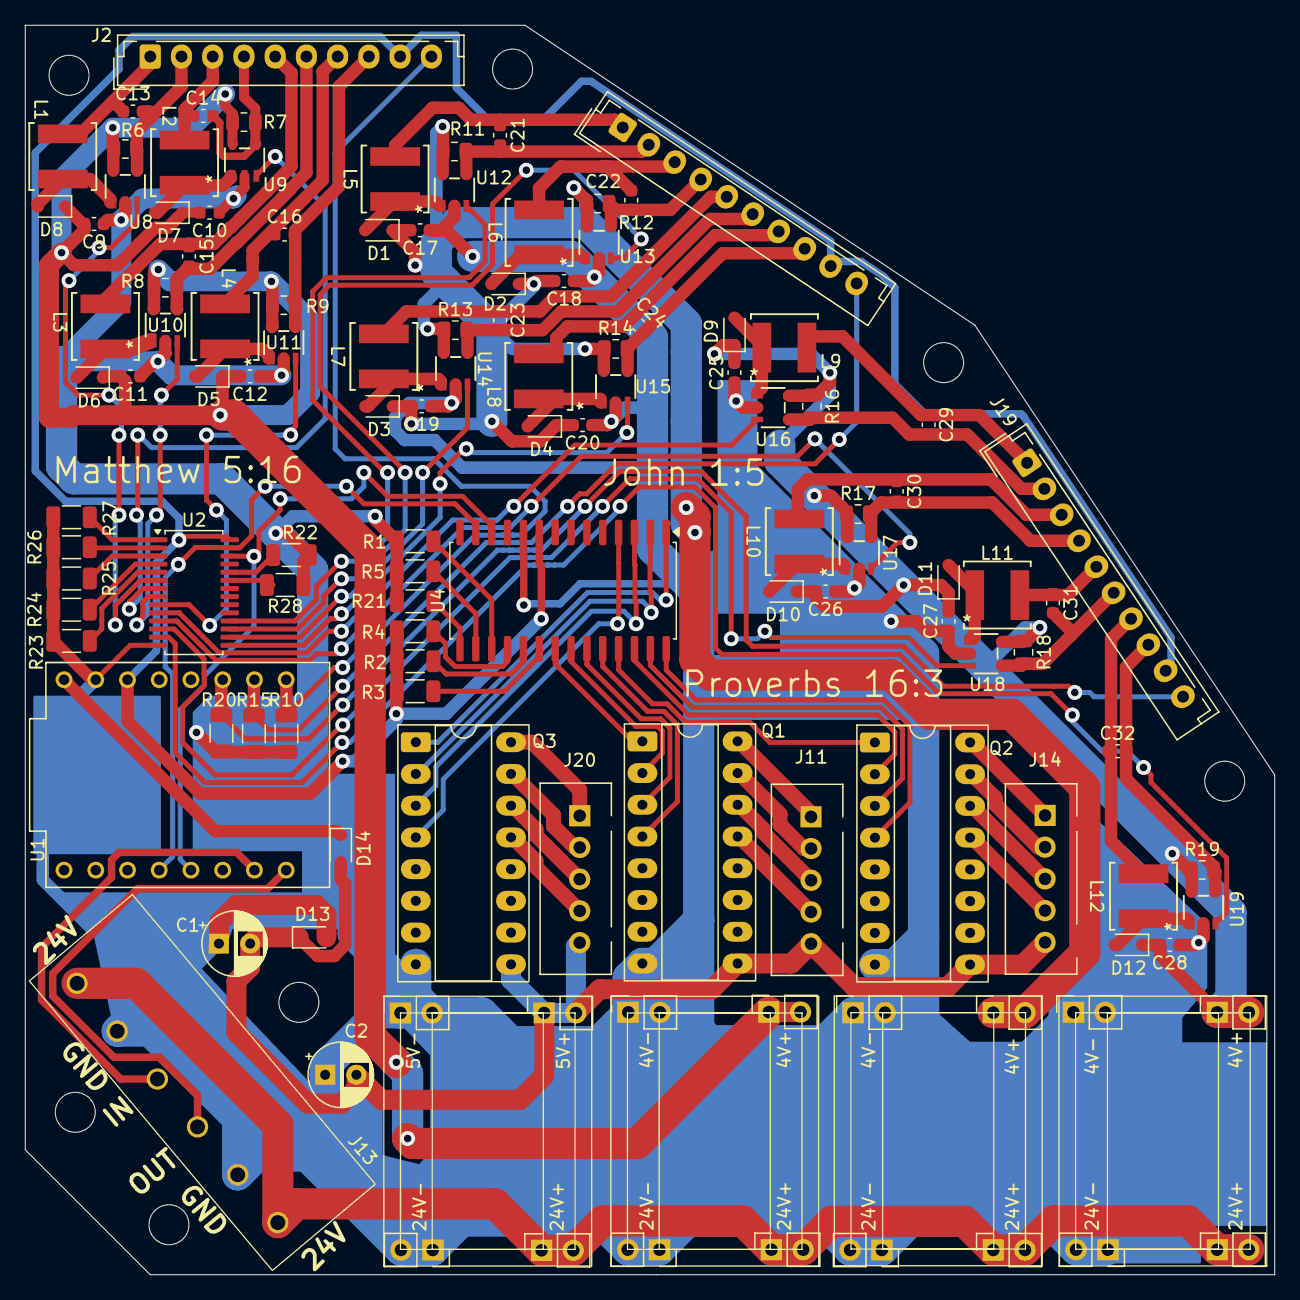
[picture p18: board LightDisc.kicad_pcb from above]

Board: 2 copper layers, 100.0 x 100.0 mm, 128 parts (0 on the bottom side), 100 nets.

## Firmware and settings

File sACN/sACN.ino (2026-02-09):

/*
Teensy 4.1

GND       VIN
0-RX      GND
1-TX      3.3V
2-S1Dir   23
3-S1Stp   22
4-S1En    21
5         20
6         19 - SCL
7         18 - SDA
8         17
9         16
10        15
11        14
12        13 - LED
3.3V      GND
24        41 - Save/Back Pushbutton
25        40 - Next Pushbutton
26-S2Dir  39 - Down Pushbutton
27-S2Stp  38 - Up Pushbutton
28-S2En   37
29-X      36 - X
30        35
31-S3Stp  34
32-S3Dir  33 - S3 En

*/

float Version = 1.0;

#include "MyFunctions.h"
#include <Wire.h>
#include <NativeEthernet.h>
#include <NativeEthernetUdp.h>
#include <AccelStepper.h>
#include <EEPROM.h>

// Navigation board, Probably Remove later?
#include <SparkFun_I2C_Expander_Arduino_Library.h>
SFE_PCA95XX io(PCA95XX_PCA9554);
int buttonUp = 1;
int buttonDown = 0;
int buttonRight = 3;
int buttonLeft = 2;
int buttonCenter = 4;
int ledBlue = 5;
int ledGreen = 6;
int ledRed = 7;

// Ethernet setup
byte mac[] = { 0xFA, 0xDE, 0xC0, 0xDE, 0x00, 0x01 };
IPAddress multicastIP(239, 255, 0, 1); // Example multicast address for Universe 1
IPAddress localIP(10, 90, 30, 92);
IPAddress subnetMask(255, 255, 255, 0);
IPAddress gateway(10, 90, 30, 253);
IPAddress dns(0, 0, 0, 0);
unsigned int localPort = 5568;
//Moved to values for Display
//uint16_t currentUniverse = 1; // Start at universe 1
//uint16_t dmxChannel = 1; // Start at DMX channel 1

EthernetUDP udp;

// --- IP Address Variables ---
byte ipAddress[4] = {10, 90, 30, 100};
int selectedOctet = 0;
// --- Button State & Debouncing Variables ---
// We need to track the state for each button to achieve a "one-shot" press
unsigned long lastDebounceTime = 0;
unsigned long debounceDelay = 50; // 50ms is a good starting point
unsigned long repeatDelay = 500;
unsigned long lastRepeatDelay = 0;
// Add variables to track the previous state of each button
int upButtonState;
int downButtonState;
int nextButtonState;
int prevButtonState;
int saveButtonState;
bool needsRedraw = true;
bool needsInvert = false;
unsigned long InvertStartTime = 0;
unsigned long lastButtonCheck = 0;
bool InvertFF = false;
const unsigned long buttonInterval = 20;  // ms
unsigned long lastAutoTime = 0;
const unsigned long AutoTime = 10000;  //10 seconds
const unsigned long ScreenOffTime = 10000;
unsigned long lastScreenOff = 0;
bool ScreenOff = false;
int AutoSteps = 7; // Number - 1
int AutoStep = 0; // Current Step
uint8_t AutoPan[] = {0 ,0, 128, 128, 255, 255, 128, 128};
uint8_t AutoTilt[] = {20 ,20, 128, 128, 230, 230, 128, 128};
uint8_t AutoDisc[] = {0 ,10, 50, 128, 255, 128, 50, 10};
uint8_t AutoLEDH[] = {0 ,10, 50, 128, 255, 128, 50, 10};
uint8_t AutoLEDS[] = {0 ,10, 255, 128, 0, 128, 255, 10};
uint8_t AutoLEDV[] = {255 ,255, 255, 255, 255, 255, 255, 255};
uint8_t AutoLEDM[] = {0 ,20, 40, 60, 180, 200, 220, 240};
uint8_t AutoFX[] = {5 ,21, 61, 0, 111, 0, 131, 0};
uint8_t AutoFXSpeed[] = {5 ,5, 5, 5, 5, 5, 5, 5};

const int LED = 13;
uint8_t DiscStepEn = 33;
uint8_t DiscStepStep = 31;
uint8_t DiscStepDir = 32;
uint8_t TiltStepEn = 28;
uint8_t TiltStepStep = 27;
uint8_t TiltStepDir = 26;
uint8_t PanStepEn = 4;
uint8_t PanStepStep = 3;
uint8_t PanStepDir = 2;
const float maxSpeed = 2500.0;  // Steps/sec (based on minDelay=400us -> ~2500 steps/sec)
const float minSpeed = 250.0;   // Steps/sec (based on maxDelay=4000us -> ~250 steps/sec)
float adjSpeed = 2500.0;
const float Pacceleration = 500.0;  // Steps/sec² for smooth ramp (adjust to reduce jerk)
const float Tacceleration = 500.0;  // Steps/sec² for smooth ramp (adjust to reduce jerk)
const float Dacceleration = 50.0;  // Steps/sec² for smooth ramp (adjust to reduce jerk)
uint8_t DiscCMD = 0;
unsigned long lastDiscAccel = 0;
const unsigned long DiscAccelTime = 10;
float discSpeed = 0.0;
float discDir = -1.0;

//Channels
uint8_t Pan1 = 0;
uint8_t Pan2 = 1;
uint8_t Tilt1 = 2;
uint8_t Tilt2 = 3;
uint8_t Disc1 = 4;
uint8_t Disc2 = 5;
uint8_t Disc3 = 6;
uint8_t L1H = 7;
uint8_t L1S = 8;
uint8_t L1V = 9;
uint8_t L1M = 10;
uint8_t L2H = 11; //7 for Single
uint8_t L2S = 12; //8 for Single
uint8_t L2V = 13; //9 for Single
uint8_t L2M = 14; //10 for Single
uint8_t L3H = 15; //7 for Single    //11 for EveryOther
uint8_t L3S = 16; //8 for Single    //12 for EveryOther
uint8_t L3V = 17; //9 for Single    //13 for EveryOther
uint8_t L3M = 18; //10 for Single   //14 for EveryOther
uint8_t L4H = 19; //7 for Single
uint8_t L4S = 20; //8 for Single
uint8_t L4V = 21; //9 for Single
uint8_t L4M = 22; //10 for Single
uint8_t L5H = 23; //7 for Single    //11 for EveryOther
uint8_t L5S = 24; //8 for Single    //12 for EveryOther
uint8_t L5V = 25; //9 for Single    //13 for EveryOther
uint8_t L5M = 26; //10 for Single   //14 for EveryOther
uint8_t L6H = 27; //7 for Single
uint8_t L6S = 28; //8 for Single
uint8_t L6V = 29; //9 for Single
uint8_t L6M = 30; //10 for Single
uint8_t L7H = 31; //7 for Single    //11 for EveryOther
uint8_t L7S = 32; //8 for Single    //12 for EveryOther
uint8_t L7V = 33; //9 for Single    //13 for EveryOther
uint8_t L7M = 34; //10 for Single   //14 for EveryOther
uint8_t L8H = 35; //7 for Single
uint8_t L8S = 36; //8 for Single
uint8_t L8V = 37; //9 for Single
uint8_t L8M = 38; //10 for Single
uint8_t L9H = 39; //7 for Single    //11 for EveryOther
uint8_t L9S = 40; //8 for Single    //12 for EveryOther
uint8_t L9V = 41; //9 for Single    //13 for EveryOther
uint8_t L9M = 42; //10 for Single   //14 for EveryOther
uint8_t L10H = 43; //7 for Single
uint8_t L10S = 44; //8 for Single
uint8_t L10V = 45; //9 for Single
uint8_t L10M = 46; //10 for Single
uint8_t L11H = 47; //7 for Single    //11 for EveryOther
uint8_t L11S = 48; //8 for Single    //12 for EveryOther
uint8_t L11V = 49; //9 for Single    //13 for EveryOther
uint8_t L11M = 50; //10 for Single   //14 for EveryOther
uint8_t L12H = 51; //7 for Single
uint8_t L12S = 52; //8 for Single
uint8_t L12V = 53; //9 for Single
uint8_t L12M = 54; //10 for Single
uint8_t PTSpeed = 55; // 11 for Single  //15 for EveryOther
uint8_t FXSel = 56; //12 for Single     //16 for EveryOther
uint8_t FXSpeed = 57; //13 for Single   //17 for EveryOther

//FX stuff
long FXRandomTime = 0;
long FXRandomLast = 0;
long FXRandomIndex = 0;
long FXSpinTime = 0;
long FXSpinLast = 0;
long FXSpinIndex = 0;
long FXMirrorTime = 0;
long FXMirrorLast = 0;
long FXMirrorIndex = 0;
long FXColorTime = 0;
long FXColorLast = 0;
long FXColorIndex = 0;

AccelStepper panStepper(AccelStepper::DRIVER, PanStepStep, PanStepDir);
AccelStepper discStepper(AccelStepper::DRIVER, DiscStepStep, DiscStepDir);
AccelStepper tiltStepper(AccelStepper::DRIVER, TiltStepStep, TiltStepDir);

bool TiltHomed = false;
int TiltCMD = 3050;
int HomePosT = 3050;
bool PanHomed = false;
int PanCMD = 7200;
int HomePosP = 7200;
const int StepsPerDMXT = 12; //6000 step is a rotation so 6000/255 = 23.59, so 12 for half tilt
const int StepsPerDMXP = 28; //8000 step is a rotation so 8000/255 = 31.37
int StepsScaled = 0;

// Variables for sACN handling
const unsigned long TIMEOUT = 2500; // 2.5 seconds timeout for top priority
unsigned long lastPacketTime = 0;
int currentPriority = 0;
byte dmxData[513]; // DMX values (512 channels + start code)

//Serial
char sBuffer[70];
const unsigned long SendTiming = 50;
unsigned long lastSendTime = 0;

//Functions
int menuPage = 0; // Current menu page
//int menuNum = 4;
const char* menuHeaders[] = {" DMX Addr.", "sACN Univs", "Ctrl Mode ", " DMX Mode ", " Pan Axis ", "Tilt Axis ", "Disc Axis ", " LEDs Hue ", "LEDs Satur", "LEDs Value", "LEDsMirror", " FX Select", " FX Speed "};
int menuType[] = {0 ,0 ,2, 3, 0, 0, 0, 0, 0, 0, 0, 0, 0}; // 0 = Integer, 1 = Yes/No, 2 = Control Mode, 3 = DMX Mode
int values[] = {0, 1, 1, 1, 0, 0, 0, 0, 0, 0, 0, 0, 0}; // Array of values: [dmxChannel, currentUniverse, DMX?]
int menuPages = 4; // or 13 if manual //sizeof(menuType) / sizeof(menuType[0]);
int DMXA = 0;
uint16_t sACNU = 1;
int ControlMode = 1;
int DMXMode = 1;

void setup() { //--------------------------------- Setup

  pinMode(PanStepEn, OUTPUT);
  pinMode(PanStepStep, OUTPUT);
  pinMode(PanStepDir, OUTPUT);
  digitalWrite(PanStepEn, LOW);
  digitalWrite(PanStepStep, LOW);
  digitalWrite(PanStepDir, LOW);
  pinMode(DiscStepEn, OUTPUT);
  pinMode(DiscStepStep, OUTPUT);
  pinMode(DiscStepDir, OUTPUT);
  digitalWrite(DiscStepEn, LOW);
  digitalWrite(DiscStepStep, LOW);
  digitalWrite(DiscStepDir, LOW);
  pinMode(TiltStepEn, OUTPUT);
  pinMode(TiltStepStep, OUTPUT);
  pinMode(TiltStepDir, OUTPUT);
  digitalWrite(TiltStepEn, LOW);
  digitalWrite(TiltStepStep, LOW);
  digitalWrite(TiltStepDir, LOW);
  pinMode(LED, OUTPUT); 
  digitalWrite(LED, HIGH);
  Serial.begin(921600);
  Serial.setTimeout(10);
  Serial.print("Version: ");
  Serial.println(Version);
  
  values[0] = EEPROM.read(0);
  DMXA = values[0];
  EEPROM.get(1, sACNU);
  values[1] = sACNU;
  //values[2] = EEPROM.read(3);
  ControlMode = values[2];
  values[3] = EEPROM.read(4);
  DMXMode = values[3];

  if (DMXA > 255){ DMXA = 0; }
  if (sACNU > 63999){ sACNU = 1; }
  if (sACNU == 0){ sACNU = 1; }
  if (ControlMode == 0){ ControlMode = 1; }
  if (ControlMode > 3){ ControlMode = 1; }
  if (DMXMode == 0){ DMXMode = 1; }
  if (DMXMode > 3){ DMXMode = 1; }

  if (ControlMode == 3){
    menuPages = 13;
  }

  // Initialize the Navigation boartd
  if (!io.begin()){
    Serial.println("Navigation button Error");
  }
  Wire.setClock(400000);

  io.pinMode(buttonUp, INPUT);
  io.pinMode(buttonDown, INPUT);
  io.pinMode(buttonLeft, INPUT);
  io.pinMode(buttonRight, INPUT);
  io.pinMode(buttonCenter, INPUT);
  io.pinMode(ledRed, OUTPUT);
  io.pinMode(ledGreen, OUTPUT);
  io.pinMode(ledBlue, OUTPUT);

  io.digitalWrite(ledRed, LOW);
  io.digitalWrite(ledGreen, LOW);
  io.digitalWrite(ledBlue, HIGH);

  // Read the initial state of the buttons
  upButtonState = io.digitalRead(buttonUp);
  downButtonState = io.digitalRead(buttonDown);
  nextButtonState = io.digitalRead(buttonRight);
  prevButtonState = io.digitalRead(buttonLeft);
  saveButtonState = io.digitalRead(buttonCenter);

  
  if (!DisplaySetup()){
    Serial.println("Display Error");
  } 
  DisplayDraw(menuPage, menuHeaders, values, menuType); // Update display

  pinMode(LED, OUTPUT);
  //analogWrite(LED, 0);
  Serial1.begin(38400);

  //Clear LEDs
  sBuffer[0] = 'D';              // Start with 'D'
  Serial1.write(sBuffer, 49);

  panStepper.setMaxSpeed(maxSpeed);
  panStepper.setAcceleration(Pacceleration);
  panStepper.setMinPulseWidth(50);
    
  discStepper.setMaxSpeed(maxSpeed);
  discStepper.setAcceleration(Dacceleration);
  discStepper.setMinPulseWidth(50);

  tiltStepper.setMaxSpeed(maxSpeed);
  tiltStepper.setAcceleration(Tacceleration);
  tiltStepper.setMinPulseWidth(50);

  // Start Ethernet on Teensy
  digitalWrite(LED, HIGH);
  Serial.println("Starting Ethernet");
  DisplayEthernet(0);
  Ethernet.begin(mac, 5);
  Serial.println("Ethernet Start Finished");
  DisplayEthernet(1);

  delay(1000);

  // start UDP
  udp.begin(localPort);
  
  // Join initial multicast group
  joinMulticastGroup(sACNU);

  lastScreenOff = millis();
}

void loop() { //--------------------------------- Main Loop
  
  // Check for incoming packets
  int packetSize = udp.parsePacket();
  if (packetSize > 0 && ControlMode == 1) {
   handlePacket(packetSize);
   if (DMXMode > 1){
    DMXModez();
   }
  }

  if (ControlMode == 2){
    Auto();
  } else if (ControlMode == 3){
    Manual();
  }

  //Call FXs
  FX();

  // Check for timeout
  if (millis() - lastPacketTime > TIMEOUT) {
    lastPacketTime = millis();
    if (Ethernet.linkStatus() != LinkOFF) {
      handleTimeout();
    }
  }

  //Screen Timeout
  if (millis() - lastScreenOff > ScreenOffTime && ScreenOff == false){
    DisplayOff();
    ScreenOff = true;
  }

  // Pan position from DMX if homed
  if (PanHomed == true){
    PanCMD = (dmxData[Pan1+DMXA] * StepsPerDMXP) + dmxData[Pan2+DMXA];
  }
  else {
    panStepper.setMaxSpeed(minSpeed);
  }
  
  // Tilt position from DMX if homed
  if (TiltHomed == true){
    TiltCMD = (dmxData[Tilt1+DMXA] * StepsPerDMXT) + dmxData[Tilt2+DMXA];
  }
  else {
    tiltStepper.setMaxSpeed(minSpeed);
  }

  if (ControlMode == 1){
  adjSpeed = map(dmxData[PTSpeed+DMXA], 0, 255, minSpeed, maxSpeed);
  } else {
    adjSpeed = maxSpeed;
  }
  panStepper.setMaxSpeed(adjSpeed);
  tiltStepper.setMaxSpeed(adjSpeed);

  panStepper.moveTo(PanCMD);  // This handles ramping to position
  tiltStepper.moveTo(TiltCMD);

  // Run steppers (non-blocking)
  discStepper.runSpeed();  // For velocity control
  panStepper.run();       // For position control with accel/decel
  tiltStepper.run();

  // Homing check (add limit switch if possible)
  if (panStepper.currentPosition() == HomePosP) {
    PanHomed = true;
    panStepper.setMaxSpeed(maxSpeed);
  }
  if (tiltStepper.currentPosition() == HomePosT) {
    TiltHomed = true;
    tiltStepper.setMaxSpeed(maxSpeed);
  }


  // Disc speed from DMX (velocity mode)
  if (millis() - lastDiscAccel > DiscAccelTime) { // If Accel time elapses, bring the speed up or down slowly, home made accel!
    lastDiscAccel = millis();
    if (DiscCMD < dmxData[Disc1+DMXA]) {
      DiscCMD = DiscCMD + 1;
    } else if (DiscCMD > dmxData[Disc1+DMXA]) {
      DiscCMD = DiscCMD - 1;
    }
  }
  discSpeed = map(DiscCMD, 0, 255, 0, maxSpeed);  // 0 to max
  if (TiltHomed == true && PanHomed == true){
    discStepper.setSpeed(discSpeed * discDir);  // Constant speed for disc
  }

  // Disc direction (only when stopped)
  if (discSpeed == 0) {
    discStepper.setSpeed(0);
    if (dmxData[Disc2+DMXA] > 127) {
      discDir = -1.0;
    } else {
      discDir = 1.0;
    }
  }

 // Send Data for Chips
  if (millis() - lastSendTime > SendTiming) {
    lastSendTime = millis();
    sBuffer[0] = 'D';              // Start with 'D'
    memcpy(&sBuffer[1], &dmxData[7], 48);
    Serial1.write(sBuffer, 49);
  }
  
  //Button Press check
  if (millis() - lastButtonCheck >= buttonInterval) {
  lastButtonCheck = millis();
  handleButtons();
  }

  //Redraw Screen if called for
 if (needsRedraw) {
   DisplayDraw(menuPage, menuHeaders, values,menuType); // Update display
   needsRedraw = false;
 }

  //Screen Invert code to not pause execution
  if (needsInvert == true){
    if (InvertFF == false){
      InvertStartTime = millis();
      DisplayInvert(true);
      InvertFF = true;
    }
    if (millis() - InvertStartTime >= 500){
      DisplayInvert(false);
      needsInvert = false;
      InvertFF = false;
    }
 }

}

void handlePacket(int packetSize) { //--------------------------------- sACN Packet
  byte buffer[638]; // Max possible size for sACN data packet
  udp.read(buffer, packetSize);

  // Parse priority and DMX data
  int priority = buffer[108]; // Priority is at byte 108 of sACN packet
  int universe = (buffer[113] << 8) | buffer[114]; // Universe at bytes 113-114

  if (universe != 1) return; // Only handle Universe 1 in this example

  // Handle priority logic
  if (priority >= currentPriority) {
    currentPriority = priority;
    lastPacketTime = millis();

    // Extract DMX data (start code at byte 125, DMX data at byte 126)
    memcpy(dmxData, &buffer[126], 512);
  }
}

void handleTimeout() {  //--------------------------------- Timeout
  Serial.println("Top priority source timed out.");
  currentPriority = 0;
  lastPacketTime = millis();
}

void DMXModez() {
  if (DMXMode == 2){
    //Pan1 through LED1 stuff left alone
    dmxData[PTSpeed+DMXA] = dmxData[11+DMXA]; 
    dmxData[FXSel+DMXA] = dmxData[12+DMXA];
    dmxData[FXSpeed+DMXA] = dmxData[13+DMXA];
    dmxData[L2H+DMXA] = dmxData[L1H+DMXA];
    dmxData[L2S+DMXA] = dmxData[L1S+DMXA];
    dmxData[L2V+DMXA] = dmxData[L1V+DMXA];
    dmxData[L2M+DMXA] = dmxData[L1M+DMXA];
    dmxData[L3H+DMXA] = dmxData[L1H+DMXA];
    dmxData[L3S+DMXA] = dmxData[L1S+DMXA];
    dmxData[L3V+DMXA] = dmxData[L1V+DMXA];
    dmxData[L3M+DMXA] = dmxData[L1M+DMXA];
    dmxData[L4H+DMXA] = dmxData[L1H+DMXA];
    dmxData[L4S+DMXA] = dmxData[L1S+DMXA];
    dmxData[L4V+DMXA] = dmxData[L1V+DMXA];
    dmxData[L4M+DMXA] = dmxData[L1M+DMXA];
    dmxData[L5H+DMXA] = dmxData[L1H+DMXA];
    dmxData[L5S+DMXA] = dmxData[L1S+DMXA];
    dmxData[L5V+DMXA] = dmxData[L1V+DMXA];
    dmxData[L5M+DMXA] = dmxData[L1M+DMXA];
    dmxData[L6H+DMXA] = dmxData[L1H+DMXA];
    dmxData[L6S+DMXA] = dmxData[L1S+DMXA];
    dmxData[L6V+DMXA] = dmxData[L1V+DMXA];
    dmxData[L6M+DMXA] = dmxData[L1M+DMXA];
    dmxData[L7H+DMXA] = dmxData[L1H+DMXA];
    dmxData[L7S+DMXA] = dmxData[L1S+DMXA];
    dmxData[L7V+DMXA] = dmxData[L1V+DMXA];
    dmxData[L7M+DMXA] = dmxData[L1M+DMXA];
    dmxData[L8H+DMXA] = dmxData[L1H+DMXA];
    dmxData[L8S+DMXA] = dmxData[L1S+DMXA];
    dmxData[L8V+DMXA] = dmxData[L1V+DMXA];
    dmxData[L8M+DMXA] = dmxData[L1M+DMXA];
    dmxData[L9H+DMXA] = dmxData[L1H+DMXA];
    dmxData[L9S+DMXA] = dmxData[L1S+DMXA];
    dmxData[L9V+DMXA] = dmxData[L1V+DMXA];
    dmxData[L9M+DMXA] = dmxData[L1M+DMXA];
    dmxData[L10H+DMXA] = dmxData[L1H+DMXA];
    dmxData[L10S+DMXA] = dmxData[L1S+DMXA];
    dmxData[L10V+DMXA] = dmxData[L1V+DMXA];
    dmxData[L10M+DMXA] = dmxData[L1M+DMXA];
    dmxData[L11H+DMXA] = dmxData[L1H+DMXA];
    dmxData[L11S+DMXA] = dmxData[L1S+DMXA];
    dmxData[L11V+DMXA] = dmxData[L1V+DMXA];
    dmxData[L11M+DMXA] = dmxData[L1M+DMXA];
    dmxData[L12H+DMXA] = dmxData[L1H+DMXA];
    dmxData[L12S+DMXA] = dmxData[L1S+DMXA];
    dmxData[L12V+DMXA] = dmxData[L1V+DMXA];
    dmxData[L12M+DMXA] = dmxData[L1M+DMXA];
  } else if (DMXMode == 3){
    //Pan1 through LED2 stuff left alone
    dmxData[PTSpeed+DMXA] = dmxData[15+DMXA]; 
    dmxData[FXSel+DMXA] = dmxData[16+DMXA];
    dmxData[FXSpeed+DMXA] = dmxData[17+DMXA];
    dmxData[L3H+DMXA] = dmxData[L1H+DMXA];
    dmxData[L3S+DMXA] = dmxData[L1S+DMXA];
    dmxData[L3V+DMXA] = dmxData[L1V+DMXA];
    dmxData[L3M+DMXA] = dmxData[L1M+DMXA];
    dmxData[L4H+DMXA] = dmxData[L2H+DMXA];
    dmxData[L4S+DMXA] = dmxData[L2S+DMXA];
    dmxData[L4V+DMXA] = dmxData[L2V+DMXA];
    dmxData[L4M+DMXA] = dmxData[L2M+DMXA];
    dmxData[L5H+DMXA] = dmxData[L1H+DMXA];
    dmxData[L5S+DMXA] = dmxData[L1S+DMXA];
    dmxData[L5V+DMXA] = dmxData[L1V+DMXA];
    dmxData[L5M+DMXA] = dmxData[L1M+DMXA];
    dmxData[L6H+DMXA] = dmxData[L2H+DMXA];
    dmxData[L6S+DMXA] = dmxData[L2S+DMXA];
    dmxData[L6V+DMXA] = dmxData[L2V+DMXA];
    dmxData[L6M+DMXA] = dmxData[L2M+DMXA];
    dmxData[L7H+DMXA] = dmxData[L1H+DMXA];
    dmxData[L7S+DMXA] = dmxData[L1S+DMXA];
    dmxData[L7V+DMXA] = dmxData[L1V+DMXA];
    dmxData[L7M+DMXA] = dmxData[L1M+DMXA];
    dmxData[L8H+DMXA] = dmxData[L2H+DMXA];
    dmxData[L8S+DMXA] = dmxData[L2S+DMXA];
    dmxData[L8V+DMXA] = dmxData[L2V+DMXA];
    dmxData[L8M+DMXA] = dmxData[L2M+DMXA];
    dmxData[L9H+DMXA] = dmxData[L1H+DMXA];
    dmxData[L9S+DMXA] = dmxData[L1S+DMXA];
    dmxData[L9V+DMXA] = dmxData[L1V+DMXA];
    dmxData[L9M+DMXA] = dmxData[L1M+DMXA];
    dmxData[L10H+DMXA] = dmxData[L2H+DMXA];
    dmxData[L10S+DMXA] = dmxData[L2S+DMXA];
    dmxData[L10V+DMXA] = dmxData[L2V+DMXA];
    dmxData[L10M+DMXA] = dmxData[L2M+DMXA];
    dmxData[L11H+DMXA] = dmxData[L1H+DMXA];
    dmxData[L11S+DMXA] = dmxData[L1S+DMXA];
    dmxData[L11V+DMXA] = dmxData[L1V+DMXA];
    dmxData[L11M+DMXA] = dmxData[L1M+DMXA];
    dmxData[L12H+DMXA] = dmxData[L2H+DMXA];
    dmxData[L12S+DMXA] = dmxData[L2S+DMXA];
    dmxData[L12V+DMXA] = dmxData[L2V+DMXA];
    dmxData[L12M+DMXA] = dmxData[L2M+DMXA];
  }
}

void Auto(){

  // Auto Timer
  if (millis() - lastAutoTime >= AutoTime){
    lastAutoTime = millis();
    AutoStep = AutoStep + 1;
    if (AutoStep > AutoSteps){
      AutoStep = 0;
    }
  }

  //DMX Control
  dmxData[Pan1+DMXA] = AutoPan[AutoStep];
  dmxData[Tilt1+DMXA] = AutoTilt[AutoStep];
  dmxData[Disc1+DMXA] = AutoDisc[AutoStep];
  dmxData[L1H+DMXA] = AutoLEDH[AutoStep];
  dmxData[L1S+DMXA] = AutoLEDS[AutoStep];
  dmxData[L1V+DMXA] = AutoLEDV[AutoStep];
  dmxData[L1M+DMXA] = AutoLEDM[AutoStep];
  dmxData[L2H+DMXA] = AutoLEDH[AutoStep];
  dmxData[L2S+DMXA] = AutoLEDS[AutoStep];
  dmxData[L2V+DMXA] = AutoLEDV[AutoStep];
  dmxData[L2M+DMXA] = AutoLEDM[AutoStep];
  dmxData[L3H+DMXA] = AutoLEDH[AutoStep];
  dmxData[L3S+DMXA] = AutoLEDS[AutoStep];
  dmxData[L3V+DMXA] = AutoLEDV[AutoStep];
  dmxData[L3M+DMXA] = AutoLEDM[AutoStep];
  dmxData[L4H+DMXA] = AutoLEDH[AutoStep];
  dmxData[L4S+DMXA] = AutoLEDS[AutoStep];
  dmxData[L4V+DMXA] = AutoLEDV[AutoStep];
  dmxData[L4M+DMXA] = AutoLEDM[AutoStep];
  dmxData[L5H+DMXA] = AutoLEDH[AutoStep];
  dmxData[L5S+DMXA] = AutoLEDS[AutoStep];
  dmxData[L5V+DMXA] = AutoLEDV[AutoStep];
  dmxData[L5M+DMXA] = AutoLEDM[AutoStep];
  dmxData[L6H+DMXA] = AutoLEDH[AutoStep];
  dmxData[L6S+DMXA] = AutoLEDS[AutoStep];
  dmxData[L6V+DMXA] = AutoLEDV[AutoStep];
  dmxData[L6M+DMXA] = AutoLEDM[AutoStep];
  dmxData[L7H+DMXA] = AutoLEDH[AutoStep];
  dmxData[L7S+DMXA] = AutoLEDS[AutoStep];
  dmxData[L7V+DMXA] = AutoLEDV[AutoStep];
  dmxData[L7M+DMXA] = AutoLEDM[AutoStep];
  dmxData[L8H+DMXA] = AutoLEDH[AutoStep];
  dmxData[L8S+DMXA] = AutoLEDS[AutoStep];
  dmxData[L8V+DMXA] = AutoLEDV[AutoStep];
  dmxData[L8M+DMXA] = AutoLEDM[AutoStep];
  dmxData[L9H+DMXA] = AutoLEDH[AutoStep];
  dmxData[L9S+DMXA] = AutoLEDS[AutoStep];
  dmxData[L9V+DMXA] = AutoLEDV[AutoStep];
  dmxData[L9M+DMXA] = AutoLEDM[AutoStep];
  dmxData[L10H+DMXA] = AutoLEDH[AutoStep];
  dmxData[L10S+DMXA] = AutoLEDS[AutoStep];
  dmxData[L10V+DMXA] = AutoLEDV[AutoStep];
  dmxData[L10M+DMXA] = AutoLEDM[AutoStep];
  dmxData[L11H+DMXA] = AutoLEDH[AutoStep];
  dmxData[L11S+DMXA] = AutoLEDS[AutoStep];
  dmxData[L11V+DMXA] = AutoLEDV[AutoStep];
  dmxData[L11M+DMXA] = AutoLEDM[AutoStep];
  dmxData[L12H+DMXA] = AutoLEDH[AutoStep];
  dmxData[L12S+DMXA] = AutoLEDS[AutoStep];
  dmxData[L12V+DMXA] = AutoLEDV[AutoStep];
  dmxData[L12M+DMXA] = AutoLEDM[AutoStep];
  dmxData[FXSel+DMXA] = AutoFX[AutoStep];
  dmxData[FXSpeed+DMXA] = AutoFXSpeed[AutoStep];

}
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

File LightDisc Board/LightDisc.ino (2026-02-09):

#include <WiFi.h>
#include <Arduino.h>
#include <Adafruit_MCP23X17.h>
#include <Adafruit_PWMServoDriver.h>

float Version = 1.16;
/*
Version
1.0 - basic working
1.1 - too slow between chips, changed serial recieve logic
1.11 - added self-healing to serial stream
1.12 - made it 115200 baud instead of 38400, also moved the serial send up, above the I2C stuff.
1.13 - dropped back to 38400 cause of communication issues, may go back up, there's some bauds between, also could have been another noise issue.
1.14 - Moved Serial recieve to after homing sequence, added 100ms timing to thermals.
1.15 - reduced freq of pwm frpm 1000 to 200, changed serial size from 65 to 49.
1.16 - back up to 400k i2c baud
*/


/*
ESP32-C3 - Configured as 'Adafruit QT Py ESP32-C3'
  X - 5 -- 5V
  X - 6    GND
  X - 7    3.3V
SDA - 8    4 - X
SCL - 9    3 - X
 X - 10    2 - Temp 3
 RX -20    1 - Temp 2
 TX -21 -- 0 - Temp 1

*/

//Thermo Variables
const unsigned long ThermalTiming = 100;
unsigned long lastThermal1 = 0;
unsigned long lastThermal2 = 0;
unsigned long lastThermal3 = 0;
int ThermistorPin1 = 0;
int ThermistorPin2 = 1;
int ThermistorPin3 = 2;
int Vo;
float Res1 = 10000;
float Res2 = 10000;
float Res3 = 10000;
float ratio;
float logR2, R2, T1, T2, T3;
float c1 = 1.009249522e-03, c2 = 2.378405444e-04, c3 = 2.019202697e-07;
float TLimit = 80.0;
char TempPacket[13];
char t1Str[5], t2Str[5], t3Str[5];

//PWM for LEDs
Adafruit_PWMServoDriver pwm = Adafruit_PWMServoDriver(0x40);
const int res = 16; //12-bit PWM vs the DMX 8 bit, so 16 is the divisor 
#define LEDR1 0 //Pin 6
#define LEDG1 1 //Pin 7
#define LEDB1 2 //Pin 8
#define LEDW1 3 //Pin 9
#define LEDR2 11 //Pin 18
#define LEDG2 10 //Pin 17
#define LEDB2 9 //Pin 16
#define LEDW2 8 //Pin 15
#define LEDR3 4 //Pin 10
#define LEDG3 5 //Pin 11
#define LEDB3 6 //Pin 12
#define LEDW3 7 //Pin 13
uint8_t LEDW1Power = 1; //Intensity of each output, as given by the DMX
uint8_t LEDR1Power = 1;
uint8_t LEDG1Power = 1;
uint8_t LEDB1Power = 1;
uint8_t LEDW2Power = 1;
uint8_t LEDR2Power = 1;
uint8_t LEDG2Power = 1;
uint8_t LEDB2Power = 1;
uint8_t LEDW3Power = 1;
uint8_t LEDR3Power = 1;
uint8_t LEDG3Power = 1;
uint8_t LEDB3Power = 1;
uint8_t H1 = 0; // DMX Input Hue
uint8_t S1 = 0; // DMX Input Saturation
uint8_t V1 = 0; // DMX Input Value
uint8_t H2 = 0; // DMX Input Hue
uint8_t S2 = 0; // DMX Input Saturation
uint8_t V2 = 0; // DMX Input Value
uint8_t H3 = 0; // DMX Input Hue
uint8_t S3 = 0; // DMX Input Saturation
uint8_t V3 = 0; // DMX Input Value

//Stepper
Adafruit_MCP23X17 mcp;
#define SS11 0 //GPA0 - Pin 21
#define SS12 1 //GPA1 - Pin 22
#define SS13 2 //GPA2 - Pin 23
#define SS14 3 //GPA3 - Pin 24
#define SS21 4 //GPA4 - Pin 25
#define SS22 5 //GPA5 - Pin 26
#define SS23 6 //GPA6 - Pin 27
#define SS24 7 //GPA7 - Pin 28
#define SS31 8 //GPB0 - Pin 0
#define SS32 9 //GPB1 - Pin 1
#define SS33 10 //GPB2 - Pin 2
#define SS34 11 //GPB3 - Pin 3
int SS1step = 0;
bool Stepper1Homed = false;
int Step1CMD = 0;
int Step1Pos = 1023;
int Step1Dif = 0;
int SS2step = 0;
bool Stepper2Homed = false;
int Step2CMD = 0;
int Step2Pos = 1023;
int Step2Dif = 0;
int SS3step = 0;
bool Stepper3Homed = false;
int Step3CMD = 0;
int Step3Pos = 1023;
int Step3Dif = 0;
const unsigned long StepTiming = 1;
unsigned long lastStep1Time = 0;
unsigned long lastStep2Time = 0;
unsigned long lastStep3Time = 0;
int StepsPerDMX = 4; //8 probably full rotation
int StepsScaled = 0;

//DMX Data
#define BUFFER_SIZE 49  // Define the maximum buffer size
bool newData = false;
int bufferIndex = 0;
char serialBuffer[BUFFER_SIZE];
char sBuffer[70];
int n;

void setup() {
  WiFi.mode(WIFI_OFF);
  btStop();
  Wire.begin(8, 9);
  Wire.setClock(400000);
  Serial.begin(9600);
  delay(500);
  Serial.println("Begin");
  Serial.print("Version: ");
  Serial.println(Version);
  Serial0.begin(38400); //115200
  pinMode(ThermistorPin1, INPUT); 
  pinMode(ThermistorPin2, INPUT); 
  pinMode(ThermistorPin3, INPUT); 
  
  if (!mcp.begin_I2C()) {
    Serial.println("MCP Error.");
  }

  mcp.pinMode(SS11, OUTPUT);
  mcp.pinMode(SS12, OUTPUT);
  mcp.pinMode(SS13, OUTPUT);
  mcp.pinMode(SS14, OUTPUT);
  mcp.pinMode(SS21, OUTPUT);
  mcp.pinMode(SS22, OUTPUT);
  mcp.pinMode(SS23, OUTPUT);
  mcp.pinMode(SS24, OUTPUT);
  mcp.pinMode(SS31, OUTPUT);
  mcp.pinMode(SS32, OUTPUT);
  mcp.pinMode(SS33, OUTPUT);
  mcp.pinMode(SS34, OUTPUT);

  if (!pwm.begin()){
    Serial.println("PCA Error");
  }

  pwm.setPWMFreq(200);
  pwm.setPWM(LEDR1, 0, 4096); //All off
  pwm.setPWM(LEDG1, 0, 4096); 
  pwm.setPWM(LEDB1, 0, 4096); 
  pwm.setPWM(LEDW1, 0, 4096); 
  pwm.setPWM(LEDR2, 0, 4096); 
  pwm.setPWM(LEDG2, 0, 4096); 
  pwm.setPWM(LEDB2, 0, 4096); 
  pwm.setPWM(LEDW2, 0, 4096); 
  pwm.setPWM(LEDR3, 0, 4096); 
  pwm.setPWM(LEDG3, 0, 4096); 
  pwm.setPWM(LEDB3, 0, 4096); 
  pwm.setPWM(LEDW3, 0, 4096); 


}
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
